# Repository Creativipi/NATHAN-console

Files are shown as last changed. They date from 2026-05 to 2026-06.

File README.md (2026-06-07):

# NATHAN Console

NATHAN Logo

## How it began

The NATHAN console was born from a desire to create something meaningful for an incredible person: **Nathan Therrien**.

I met Nathan in high school. He was one of those rare people who naturally brighten the world around them. Always smiling, always the first to say hello, to crack a joke, to make everyone around him feel good. We shared the same class in our final year, and even then, I was amazed by his radiant energy.

After high school, life took us in different directions. But I kept following Nathan online, especially through his Facebook page, where he shares videos of his musical explorations. Because yes, on top of everything else, **Nathan is an outstanding musician** and a passionate synthesizer enthusiast.

One morning in year 2022, Nathan made a post looking for help with 3D printing and soldering. At that time, I was just diving into the world of programming, microcontrollers, and digital fabrication. I was eager to learn and build something real. The moment I saw his message, I knew: **this was the project I had been waiting for**.

Working with Nathan, someone I had admired for years, gave me the perfect opportunity to grow my skills while collaborating with someone truly inspiring. He would be part of the process: designing the sounds, shaping the ideas, and even learning to code. From the start, the goal was clear: **build something together that he could one day fully own**.

Since 2022, this journey has become a shared adventure. Today, I’m proud to present the first version of the console:
**NATHAN — Narrative Audio Terminal for Humans with Alternative Navigation**.

As time becomes more limited for me, my hope is to pass the torch. I want the community to take this project further, to make it bigger, better, and even more inclusive.

---

## What is NATHAN?

**NATHAN** is an open source game console powered by a Raspberry Pi Pico, specifically designed for blind or visually impaired players.

Inspired by the form of an Xbox controller, the device includes:

* 5 tactile buttons
* 5 LED indicators
* An integrated audio output
  Together, these features enable an immersive and fully accessible gaming experience.

---

## Features

* 🎮 **Ergonomic form** – Inspired by the Xbox controller for comfortable use
* 🔘 **5 physical buttons** – Easily distinguishable for gameplay
* 💡 **5 LED indicators** – Optional visual feedback
* 🔊 **Audio output** – For immersive, sound-based gameplay
* ♿ **Inclusive game design** – Every game is made for accessibility

---

## Game Concept

Each game on the NATHAN console features a **blind protagonist named Nathan**.

The current flagship game, **NATHAN: Glassbreaker**, puts you in the role of Nathan, a hero who fights and navigates *only* through sound. It's a game where your ears become your eyes, and audio becomes your primary interface with the world. A game felt instead of seen.

---

## Open Source & Community

NATHAN is proudly open source.

This project is a call to creators, developers, makers, and dreamers:
**Let’s build accessible games together.**

Whether you want to:

* Design new games tailored for blind players
* Improve the hardware or firmware
* Suggest ideas to enhance the console
  Your contribution is welcome.

---

## Name Meaning

> **NATHAN** = *Narrative Audio Terminal for Humans with Alternative Navigation*

A console built around sound, for a hero and a community that navigates the world differently.

---

> 🎙️ *Together, let’s make gaming accessible to everyone.*

---

## 📚 Documentation & gouvernance

Toute la documentation projet vit dans [`docs/`](./docs/) :

- **[`docs/README.md`](./docs/README.md)** — *commencez ici* (parcours de lecture).
- **[Journal des décisions — ADR](./docs/decisions/README.md)** — *pourquoi* le projet est ainsi, et son évolution dans le temps.
- **[Specs](./docs/specs/)** · **[Planification & GANTT](./docs/planning/)** · **[Architecture](./docs/architecture/)**.
- **[CONTRIBUTING.md](./CONTRIBUTING.md)** — comment contribuer et **tracer une décision**.

---

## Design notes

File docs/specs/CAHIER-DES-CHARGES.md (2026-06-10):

# Cahier des Charges — Projet NATHAN Console (v2.0)

**Projet :** NATHAN — Narrative Audio Terminal for Humans with Alternative Navigation
**Version du document :** 2.0
**Date :** 2026-03-05
**Auteur :** Arthur Olivier Fortin
**Statut :** Phase de conception majeure

---

## Table des matières

1. [Contexte et vision du projet](#1-contexte-et-vision-du-projet)
2. [État actuel du projet (v1.0)](#2-état-actuel-du-projet-v10) — *inclut jeu existant GlassBreaker et IDE*
3. [Objectifs du projet majeur (v2.0)](#3-objectifs-du-projet-majeur-v20)
4. [Public cible](#4-public-cible)
5. [Équipes, rôles et stratégie de développement parallèle](#5-équipes-rôles-et-stratégie-de-développement-parallèle)
6. [Spécifications hardware (v2.0)](#6-spécifications-hardware-v20)
7. [Spécifications firmware et logiciel bas niveau](#7-spécifications-firmware-et-logiciel-bas-niveau)
8. [Spécifications du game engine](#8-spécifications-du-game-engine)
9. [Spécifications du premier jeu — La Maison de Nathan](#9-spécifications-du-premier-jeu--la-maison-de-nathan)
10. [Système de mini-jeux](#10-système-de-mini-jeux)
11. [Contraintes et risques techniques](#11-contraintes-et-risques-techniques)
12. [Planification par workstreams et dépendances](#12-planification-par-workstreams-et-dépendances)
13. [Budget](#13-budget)
14. [Livrables](#14-livrables)

---

## 1. Contexte et vision du projet

### 1.1 Origine

Le projet NATHAN est né en 2022 d'une collaboration entre Arthur Olivier Fortin et une personne non-voyante, musicien et passionné de synthétiseurs. L'objectif initial était de concevoir une console de jeu entièrement accessible aux personnes non-voyantes, dans laquelle le son et les sensations tactiles remplacent intégralement l'image. Le projet est réalisé en partenariat avec l'APHVE (Association des Personnes Handicapées Visuelles de l'Estrie), qui accompagne l'équipe avec un groupe d'utilisateurs non-voyants tout au long du développement.

### 1.2 Mission

Créer une console de jeu **open-source**, **abordable** et **inclusive**, où l'expérience est entièrement auditive et haptique. La console doit permettre à un utilisateur non-voyant de jouer les yeux fermés, avec une immersion complète par le son spatial 3D et le retour vibratoire directionnel.

### 1.3 Vision long terme

- Être la première console de jeu grand public dédiée aux personnes ayant une déficience visuelle.
- Permettre aux utilisateurs de **créer leurs propres mini-jeux** sans barrière technique (MicroPython).
- Constituer une **plateforme pédagogique** : initiation à la programmation pour les personnes non-voyantes.
- Rester open-source pour favoriser la contribution communautaire.

---

## 2. État actuel du projet (v1.0)

### 2.1 Ce qui est complété

| Composant | État | Détails |
|---|---|---|
| Modèles 3D boîtier | ✅ Complet | 3 pièces SolidWorks (.SLDPRT, importables dans Onshape — géométrie conservée), STL générés |
| PCB KiCAD | ✅ Complet | Gerbers prêts pour fabrication |
| BOM (liste de matériaux) | ✅ Documenté | Composants sourcés |
| Documentation README | ✅ Rédigé | Histoire, vision, fonctionnalités |

### 2.2 Matériel actuel (v1.0)

| Composant | Spécification |
|---|---|
| Microcontrôleur | Raspberry Pi Pico (RP2040) |
| Boutons | 5 (3 arcade 30mm + 2 micro switches) |
| LEDs | 5 (indicateurs visuels) |
| Moteurs haptiques | 2 (moteurs Xbox rumble) |
| Audio | Jack stéréo 3.5mm |
| Stockage | Module micro SD |
| Alimentation | 3x piles AA |
| Potentiomètre | WH148 1kΩ |

### 2.3 Ce qui n'existe pas encore (côté console v2.0)

- Firmware embarqué : **non démarré** (à écrire en C/C++, MCU à déterminer)
- Game engine spatial : **non démarré**
- IDE mini-jeux (intégration NATHAN) : **en cours** (voir 2.5)

### 2.4 Jeu existant — GlassBreaker (CircuitPython, Raspberry Pi Pico)

Un jeu complet est déjà fonctionnel dans le dépôt `NATHAN-code`. Il tourne sur le **Raspberry Pi Pico** en **CircuitPython 8.x** et constitue la référence directe pour l'architecture des mini-jeux futurs.

**Dépôt :** `C:\Users\arthu\OneDrive\NATHAN\NATHAN-code` (GlassBreaker Safe CP)

#### Architecture du jeu existant

```
GlassBreaker Safe CP/
├── main.py              # Orchestre tous les managers
├── input/buttons.py     # ButtonManager — lecture GPIO
├── output/audio.py      # AudioManager — PWM 22050Hz mono
├── output/leds.py       # LEDManager — 7 LEDs
├── output/motors.py     # MotorManager — 2 moteurs rumble
├── game/logic.py        # GameLogic + GameState
├── game/menu.py         # MenuSystem + MenuExtension
├── utils/memory.py      # MemoryManager — scores SD card
├── sounds/              # Fichiers WAV sur carte SD
└── lib/                 # Bibliothèques Adafruit CircuitPython
```

#### Mécaniques de jeu

- **Type :** Jeu de réaction bouton (audio-first)
- **5 modes :** Arcade (sons), Voice (voix), Reverse, Light (visuel), Megamix (aléatoire)
- **Difficulté progressive :** `timeout = max(0.5, 1.0 - (0.001 × score))`
- **Jalons :** Annonces audio à 25, 50, 75, 100 points
- **Persistance :** High scores par mode sur carte SD (FAT32)

#### Ce que cela implique pour v2.0

| Aspect | GlassBreaker (v1) | NATHAN v2.0 |
|---|---|---|
| Langage jeu | CircuitPython | C/C++ (game engine) |
| Langage mini-jeux | CircuitPython | MicroPython (quasi-identique) |
| Audio | PWM mono 22050 Hz | I2S stéréo binaural HRTF |
| Entrées | 5 boutons | 2 joysticks + boutons |
| Haptique | 2 moteurs (on/off) | 5 moteurs arc (PWM intensité) |
| Pattern module | Manager + MenuExtension | HAL + API game engine |

> **Note de compatibilité :** CircuitPython et MicroPython partagent ~95% de leur syntaxe. Les mini-jeux écrits pour v2.0 s'inspireront directement des modules GlassBreaker. Le `MenuExtension` pattern existant (classe avec `run()` et métadonnées) devient le modèle du format mini-jeu MicroPython.

#### Pattern MenuExtension (référence pour le format mini-jeu)

```python
# Modèle inspiré de game/menu.py (GlassBreaker)
class MonMiniJeu:
    META = {
        "title": "Mon Mini-Jeu",
        "author": "Arthur",
        "description": "Description audio du jeu"
    }

    def __init__(self, managers):
        self.audio = managers["audio"]
        self.buttons = managers["buttons"]
        self.motors = managers["motors"]

    def run(self):
        """Boucle principale — retourne True si succès, False si échec"""
        pass
```

### 2.5 IDE de programmation (Electron + React + TypeScript)

L'IDE fait partie intégrante du projet NATHAN. C'est l'application desktop qui permet aux utilisateurs (y compris non-voyants) de programmer et de transférer des mini-jeux sur la console.

**Stack :** Electron 28 + React 18 + TypeScript 5.3 + Vite 5

#### Ce qui est déjà implémenté dans l'IDE

| Fonctionnalité | État | Détail |
|---|---|---|
| Éditeur de code multi-onglets | ✅ Complet | Textarea + coloration syntaxique custom |
| Explorateur de fichiers (sidebar) | ✅ Complet | Arborescence avec create/delete |
| Recherche & remplacement | ✅ Complet | Case-insensitive, replace-all |
| Terminal intégré | ✅ Complet | Exécution de commandes shell avec streaming |
| Accessibilité vocale (TTS) | ✅ Complet | Web Speech API, **français par défaut (fr-FR)** |
| Screen reader (ARIA live) | ✅ Complet | Annonces assistives |
| Raccourcis clavier | ✅ Complet | Ctrl+F, Ctrl+S, Ctrl+Shift+P, etc. |
| Palette de commandes | ✅ Complet | Ctrl+Shift+P |
| Maestro backend (IA, C# .NET) | ✅ Intégré | Sidecar HTTP, agent "Jarvis" (ask) |
| Coloration syntaxique TypeScript/JS | ✅ Complet | Tokenizer regex custom |

#### Ce qui reste à développer dans l'IDE pour NATHAN

| Fonctionnalité | Priorité | Notes |
|---|---|---|
| Coloration syntaxique MicroPython | Critique | Remplacer/compléter le tokenizer TS |
| Auto-complétion API `nathan.*` | Critique | Nécessite Monaco Editor ou extension |
| Communication USB série (console) | Critique | Web Serial API ou `serialport` npm |
| Upload de `.py` vers carte SD via USB | Critique | Dépend de la communication USB |
| Visualisateur de scène 2D (sons spatiaux) | Haute | Drag & drop, coordonnées x/y/z |
| Simulation audio WebAudio HRTF | Moyenne | Aperçu avant envoi sur console |
| Gestionnaire de mini-jeux (liste SD) | Haute | Lecture liste depuis console |
| Mode d'affichage accessible (grand texte, contraste) | Haute | Accessibilité DV |

> L'IDE est développé dans le cadre de ce projet sous `ide/`. L'intégration avec la console NATHAN se fait via le protocole USB CDC défini dans la section 7.4.

---

## 3. Objectifs du projet majeur (v2.0)

Le projet v2.0 constitue une **refonte complète** articulée autour de quatre axes :

### Axe 1 — Refonte hardware
Remplacer le Raspberry Pi Pico par un **microcontrôleur adapté** (choisi après benchmark), ajouter **2 joysticks analogiques**, **5 moteurs de vibration en arc**, et migrer vers une **batterie LiPo USB-C rechargeable**.

### Axe 2 — Game engine embarqué
Développer un moteur de jeu en **C/C++** tournant sur le microcontrôleur choisi, avec un système de placement 2D+hauteur permettant le calcul automatique d'**audio spatial binaural (HRTF)**.

### Axe 3 — Premier jeu : La Maison de Nathan
Développer le jeu de démonstration de la console : un jeu entièrement auditif et haptique mettant en scène Nathan, un aveugle, dans sa maison.

### Axe 4 — Système de mini-jeux
Permettre aux utilisateurs de programmer et jouer à des mini-jeux écrits en **MicroPython** via l'IDE du projet.

---

## 4. Public cible

### 4.1 Utilisateurs finaux (joueurs)

- **Primaire :** Personnes non-voyantes ou malvoyantes, tous âges
- **Secondaire :** Personnes voyantes souhaitant une expérience sensorielle immersive

### 4.2 Utilisateurs créateurs (programmeurs de mini-jeux)

- **Primaire :** Personnes non-voyantes apprenant la programmation
- **Secondaire :** Développeurs souhaitant créer du contenu pour la plateforme
- **Niveau requis :** Débutant (MicroPython simplifié, interface graphique)

### 4.3 Contraintes d'accessibilité prioritaires

- Toute interface de jeu doit fonctionner **sans retour visuel**
- Tous les menus et interactions doivent être **entièrement navigables au son**
- Le boîtier doit être **ergonomique** et les contrôles **facilement différenciables au toucher**

---

## 5. Équipes, rôles et stratégie de développement parallèle

### 5.1 Composition des équipes

| Équipe | Code | Profil | Responsabilité |
|---|---|---|---|
| **Électrique** | ELEC | Génie électrique | Schéma, PCB, boîtier, soudure, validation matérielle |
| **Engine** | ENG | Génie informatique | Game engine, scènes, collisions, bâton, MicroPython, HAL |
| **Audio spatial** | AUD | Génie informatique (spécialisé signal/audio) | Pipeline HRTF, mix binaural, évaluation software vs DSP |
| **Jeu / Contenu** | JEU | Génie informatique / design | Design des pièces, mécaniques de jeu, banque de sons, narration |

### 5.2 Principe fondamental : zéro temps d'attente entre équipes

Le plan de développement est conçu pour que **aucune équipe ne soit bloquée** par une autre. Cela repose sur trois stratégies :

#### Stratégie A — Manette de substitution (découple ELEC ↔ ENG/JEU)

Dès le **jour 1** du projet, les équipes logicielles utilisent une **manette USB grand public** (type DualShock 4 / Xbox One, ~30$ CAD) pour développer et tester toute la logique de jeu.

Un module **InputMapper** abstrait complètement le matériel :

```
┌───────────────────────────────────────────────┐
│                 Game Engine                     │
│                                                 │
│    scene.update(input, dt)                      │
│         │                                       │
│    ┌────▼─────┐                                 │
│    │InputMapper│  ← Interface abstraite          │
│    └────┬─────┘                                 │
│         │                                       │
│    ┌────┴──────────────┬──────────────────┐     │
│    │                   │                  │     │
│  GamepadMapper    NathanMapper       DebugMapper│
│  (DualShock/Xbox) (manette réelle)   (clavier)  │
│  PHASE 1-2        PHASE 3+           DEBUG      │
└───────────────────────────────────────────────┘
```

| Implémentation | Utilisée par | Phase | Description |
|---|---|---|---|
| `GamepadMapper` | ENG, JEU, AUD | Phases 1-2 | Manette USB standard. Joystick L/R mappés directement, vibration mono simulée. |
| `DebugMapper` | ENG | Toutes | Clavier + souris pour tests rapides sans manette |
| `NathanMapper` | ENG, ELEC | Phase 3+ | Manette NATHAN réelle. Joysticks ADC, 5 moteurs PWM, boutons GPIO. |

**Mapping de substitution (GamepadMapper):**

| Contrôle NATHAN | Substitut DualShock/Xbox |
|---|---|
| Joystick gauche | Joystick gauche (identique) |
| Joystick droite | Joystick droite (identique) |
| Boutons A/B/C | ×/○/△ (ou A/B/Y) |
| Gâchettes L1/R1 | L1/R1 (identique) |
| 5 moteurs arc | Vibration unique du gamepad (intensité = moteur central) |
| Start/Select | Start/Select (identique) |

**Pour le haptique**, le gamepad n'a qu'un moteur. Le GamepadMapper simule les 5 moteurs en arc par :
- Vibration unique pour tout contact de bâton
- Logs console indiquant quel moteur NATHAN serait activé (pour debug)
- La validation réelle des 5 moteurs se fait à la Phase 3 (intégration)

#### Stratégie B — Développement audio PC-first (découple AUD ↔ ELEC)

Le développeur audio ne touche **jamais** au microcontrôleur avant la Phase 3. Tout le développement HRTF se fait sur PC :

```
Phase 1 : Recherche + prototypage PC (C/C++ + miniaudio ou libsoundio)
Phase 2 : Module audio spatial fonctionnel sur PC, testé au casque
Phase 3 : Portage vers le MCU choisi, benchmark CPU/latence
Phase 3b: Décision : software pur OU ajout DSP matériel externe
```

L'interface entre le game engine et le module audio est un **contrat** défini dès la Phase 0 (voir 5.3). Tant que le contrat est respecté, les implémentations PC et ESP32 sont interchangeables.

#### Stratégie C — Contrats d'interface (découple toutes les équipes)

Avant tout développement, les équipes définissent ensemble les **interfaces contractuelles** entre les modules. Chaque interface a une **implémentation stub** qui permet de tester sans dépendance.

### 5.3 Contrats d'interface (Phase 0 — à définir en priorité)

Les 5 contrats suivants sont les **premiers livrables du projet**. Ils doivent être définis et validés par toutes les équipes avant le début du développement.

#### Contrat 1 — InputMapper (ENG ↔ ELEC)

```c
// Abstraction des entrées : toute source d'input implémente cette interface
typedef struct {
    float left_x, left_y;     // Joystick gauche (-1.0 à 1.0)
    float right_x, right_y;   // Joystick droite (-1.0 à 1.0)
    bool buttons[9];           // A, B, C, L1, R1, L2, R2, Start, Select
    bool left_click;           // Joystick gauche appuyé
    bool right_click;          // Joystick droite appuyé
} InputState;

void input_mapper_init(void);
InputState input_mapper_read(void);
```

#### Contrat 2 — SpatialAudioEngine (ENG ↔ AUD)

```c
// Abstraction audio : le game engine place des sons, l'implémentation les rend binauraux
typedef int SoundHandle;

void spatial_audio_init(int sample_rate, int max_sources);
void spatial_audio_shutdown(void);

SoundHandle spatial_audio_play(const char* wav_path, float x, float y, float z, bool loop);
void spatial_audio_stop(SoundHandle h);
void spatial_audio_set_position(SoundHandle h, float x, float y, float z);
void spatial_audio_set_volume(SoundHandle h, float vol);

void spatial_audio_update_listener(float px, float py, float orientation_deg);
void spatial_audio_render(int16_t* stereo_buffer, int frame_count);

// Ambiance (non spatialisé, stéréo direct)
void spatial_audio_play_ambient(const char* wav_path, float volume);
void spatial_audio_stop_ambient(void);
```

**Implémentations prévues :**

| Implémentation | Utilisée par | Phase | Backend |
|---|---|---|---|
| `StubAudio` | ENG | Phase 1 | Pas de son, logs console uniquement |
| `PCAudio` | AUD, JEU | Phase 1-2 | `miniaudio` + HRTF sur PC |
| `EmbeddedAudio` | Tous | Phase 3+ | I2S + DAC + HRTF embarqué (MCU choisi après benchmark) |

#### Contrat 3 — HapticEngine (ENG ↔ ELEC)

```c
// Abstraction haptique : 5 moteurs logiques en arc
// Motor IDs : 0=extrême gauche, 1=gauche, 2=centre, 3=droite, 4=extrême droite

void haptic_init(void);
void haptic_pulse(int motor_id, float intensity, int duration_ms);
  // motor_id: 0-4, intensity: 0.0-1.0
void haptic_sweep(float direction, float intensity);
  // direction: -1.0 (gauche) → 1.0 (droite)
void haptic_pattern(const char* pattern_name);
  // Patterns prédéfinis: "cane_wall", "cane_floor", "cane_sweep", "hit", "strum"
void haptic_stop_all(void);
```

**Implémentations prévues :**

| Implémentation | Phase | Comportement |
|---|---|---|
| `StubHaptic` | Phase 1 | Logs console uniquement |
| `GamepadHaptic` | Phase 1-2 | Vibration unique du gamepad USB |
| `NathanHaptic` | Phase 3+ | 5 moteurs PWM réels via GPIO du MCU choisi |

#### Contrat 4 — StorageProvider (ENG)

```c
void storage_init(void);
bool storage_file_exists(const char* path);
int  storage_read_file(const char* path, uint8_t* buffer, int max_size);
int  storage_write_file(const char* path, const uint8_t* data, int size);
char** storage_list_dir(const char* path, int* count);
```

#### Contrat 5 — MiniGameRunner (ENG)

```c
typedef struct {
    char title[64];
    char author[32];
    char description[128];
} MiniGameMeta;

bool minigame_load(const char* dir_path);
MiniGameMeta minigame_get_meta(void);
bool minigame_setup(void);
bool minigame_loop(void);  // retourne false quand le mini-jeu se termine
void minigame_unload(void);
```

### 5.4 Matrice de responsabilité (RACI)

| Livrable | ELEC | ENG | AUD | JEU |
|---|---|-----|-----|-----|
| Schéma / PCB (MCU choisi) | **R** | C | — | — |
| Boîtier v2.0 (Onshape) | **R** | C | — | — |
| Soudure et validation matérielle | **R** | — | — | — |
| Contrats d'interface (Phase 0) | C | **R** | C | I |
| InputMapper (toutes implémentations) | C | **R** | — | — |
| Game engine (scènes, collisions, bâton) | — | **R** | — | I |
| Pipeline HRTF (recherche + implémentation) | — | I | **R** | — |
| Portage audio embarqué | C | I | **R** | — |
| Intégration MicroPython | — | **R** | — | I |
| Design des pièces du jeu | — | I | I | **R** |
| Banque de sons et musiques | — | — | C | **R** |
| Narration audio (tutoriel, voix personnage) | — | — | — | **R** |
| Mécaniques guitare/batterie | — | C | C | **R** |
| Tests d'intégration finale | C | **R** | C | C |
| Tests utilisateur (groupe DV via APHVE) | I | C | C | **R** |
| IDE de programmation | — | **R** | — | C |

> **R** = Responsable, **C** = Consulté, **I** = Informé

---

## 6. Spécifications hardware (v2.0)

### 6.1 Microcontrôleur — À déterminer

Le microcontrôleur sera choisi **après le benchmark du jeu sur PC**, qui mesurera les besoins réels en CPU, RAM et I/O. Cette décision est le jalon clé du chemin critique (voir `TACHES.md`).

**Besoins minimaux identifiés :**

| Paramètre | Besoin minimum | Justification |
|---|---|---|
| CPU | >= 2 cœurs, >= 160 MHz | Un cœur dédié au rendu audio HRTF, un à la logique de jeu |
| RAM | >= 4 MB (PSRAM) | Tables HRTF (~1 MB) + buffers audio + game engine + MicroPython |
| Flash | >= 8 MB | Firmware + interpréteur MicroPython |
| I2S | >= 1 interface stéréo | Connexion au DAC audio externe |
| ADC | >= 4 canaux, >= 10 bits | 2 joysticks × 2 axes |
| PWM | >= 5 canaux | 5 moteurs haptiques individuels |
| USB | USB OTG ou CDC natif | Communication avec l'IDE (port série virtuel) |
| SPI | >= 1 | Lecteur carte micro SD |
| GPIO | >= 9 numériques | 7 boutons + 2 clicks joystick |

**Candidats préliminaires** (analyse détaillée dans le MIP) :

| MCU | CPU | RAM | I2S | USB | Prix (~) |
|-----|-----|-----|-----|-----|---|
| ESP32-S3 | 2× 240 MHz | 8 MB PSRAM | 2× | USB OTG natif | ~5$ |
| RP2350 | 2× 150 MHz | 520 KB + ext | 2× | USB 1.1 | ~1$ |
| STM32H7 | 1× 480 MHz | 1 MB + ext | 2× | USB OTG | ~10$ |

> Le choix final sera documenté dans un **rapport de justification quantitatif** basé sur le benchmark PC (voir `TACHES.md`, jalon "Choix du MCU").

### 6.2 Système audio

**Le DAC audio sera choisi en même temps que le MCU.** Les besoins sont :

| Paramètre | Besoin |
|---|---|
| Interface | I2S (compatible avec le MCU choisi) |
| Résolution | >= 16 bits, >= 44.1 kHz |
| SNR | >= 80 dB |
| Sortie | Jack stéréo 3.5mm (casque uniquement) |

**Note importante :** Le jeu est conçu pour une écoute au **casque stéréo uniquement**. Le son spatial binaural (HRTF) requiert un casque pour l'effet 3D.

#### Pipeline audio spatial

```
Positions 3D des sons (via SpatialAudioEngine)
        ↓
Calcul azimut/élévation/distance
        ↓
Application HRTF (lookup table, MIT KEMAR ou équivalent open-source)
        ↓
Mix audio binaural (canal L + canal R)
        ↓
Buffer DMA → I2S → DAC → Jack 3.5mm
```

#### Format audio des assets

- Samples : **WAV 16 bits, 44.1 kHz, mono** (le moteur applique la spatialisation)
- Musiques d'ambiance : **WAV 16 bits, 44.1 kHz, stéréo** (non spatiales, lecture directe)
- Stockage sur carte micro SD

### 6.3 Système haptique — 5 moteurs en arc

#### Topologie

Les 5 moteurs vibrants sont disposés en arc de cercle dans le corps de la manette :

```
Position physique :  [M0]  [M1]  [M2]  [M3]  [M4]
Direction simulée :  ←←   ←     ↑     →     →→
```

#### Spécifications moteurs

| Paramètre | Valeur |
|---|---|
| Type | Moteur à vibration excentrique (ERM) ou LRA |
| Tension nominale | 3V |
| Contrôle | PWM individuel par canal (intensité variable) |
| Driver | MOSFET N-CH par moteur (ex: 2N7002) OU DRV2605L (recommandé) |
| Fréquence PWM | 1 kHz minimum |

#### Cas d'usage

| Interaction | Moteurs activés | Pattern |
|---|---|---|
| Bâton touche mur à gauche | M0, M1 | Impulsion courte, forte |
| Bâton touche sol | M0 à M4 (tous, faible) | Vibration continue faible |
| Bâton touche obstacle à droite | M3, M4 | Impulsion courte, forte |
| Coup de bâton en combat | M0 à M4 (séquence) | Sweep directionnel |
| Guitare — strumming | M2, M3 | Vibration rhythmique |
| Drum — impact | M correspondant à la zone | Impulsion forte courte |

### 6.4 Entrées utilisateur

#### Joysticks

| Paramètre | Valeur |
|---|---|
| Quantité | 2 (gauche + droite) |
| Type | Joystick analogique double axe (modèle Xbox/PS) |
| Résolution ADC | 12 bits (0–4095) |
| Canaux requis | 4 entrées ADC (X/Y par joystick) |
| Bouton intégré | Oui (appui joystick = bouton numérique) |

#### Boutons

| Bouton | Type | Usage principal |
|---|---|---|
| A (×) | Arcade 30mm | Action principale |
| B (○) | Arcade 30mm | Action secondaire |
| C (△) | Arcade 30mm | Action tertiaire / menu |
| L1 | Micro switch | Gâchette gauche |
| R1 | Micro switch | Gâchette droite |
| Start | Bouton tactile | Menu / pause |
| Select | Bouton tactile | Retour / annuler |

### 6.5 Alimentation

| Paramètre | Besoin |
|---|---|
| Batterie | LiPo 1S (3.7V) — capacité min. 2000 mAh |
| Connecteur de charge | USB-C |
| Protection | Surcharge, décharge profonde, court-circuit |
| Régulateur | LDO 3.3V pour le MCU |
| Autonomie cible | >= 4 heures en usage typique |

> L'estimation de consommation détaillée sera calculée une fois le MCU et le DAC choisis.

### 6.6 Connectivité

| Interface | Usage |
|---|---|
| USB-C | Charge + connexion à l'IDE NATHAN (USB CDC) |
| Wi-Fi 2.4 GHz | Mise à jour OTA (optionnel v2.0) |
| Micro SD | Stockage assets audio, jeux, mini-jeux |

### 6.7 Boîtier (refonte ergonomique)

#### Contraintes de refonte

- Intégrer 2 joysticks (gauche + droite)
- Intégrer 5 moteurs en arc dans les poignées
- Passer à une batterie LiPo + port USB-C
- Conserver l'inspiration Xbox pour l'ergonomie
- Rester fabricable par impression 3D FDM
- **Dimensions maximales :** Tenir dans une main adulte (largeur ~16 cm)

#### Fichiers à mettre à jour

- `CAD_Files/Console/NATHAN-console-asm.SLDASM` — refonte complète
- `CAD_Files/Console/parts/*.SLDPRT` — toutes les pièces
- `3D Print Models/*.STL` — regenerer depuis les nouveaux SLDPRT
- `CAD_Files/PCB/` — nouveau schéma et PCB pour le MCU choisi

---

## 7. Spécifications firmware et logiciel bas niveau

### 7.1 Environnement de développement

| Paramètre | Valeur |
|---|---|
| SDK | Dépend du MCU choisi (ex: ESP-IDF, Pico SDK, STM32 HAL) |
| Langage principal | C / C++17 |
| Build system | CMake |
| Tests | Unity test framework (embarqué) |

> Le SDK et les outils de débogage seront déterminés après le choix du MCU.

### 7.2 Architecture firmware

```
┌─────────────────────────────────────────────────────────┐
│                      APPLICATION                         │
│  ┌─────────────┐  ┌──────────────┐  ┌────────────────┐  │
│  │  Game Engine │  │ MicroPython  │  │   USB Bridge   │  │
│  │   (C/C++)   │  │  Sandbox     │  │   (CDC)        │  │
│  └──────┬──────┘  └──────┬───────┘  └───────┬────────┘  │
│         └────────────────┴──────────────────┘            │
│  ┌─────────────────────────────────────────────────────┐ │
│  │         Contrats d'interface (section 5.3)          │ │
│  │  InputMapper | SpatialAudioEngine | HapticEngine    │ │
│  └─────────────────────────────────────────────────────┘ │
│  ┌─────────────────────────────────────────────────────┐ │
│  │              Hardware Abstraction Layer (HAL)        │ │
│  │  NathanMapper | ESP32Audio | NathanHaptic | Storage │ │
│  └─────────────────────────────────────────────────────┘ │
│  ┌──────────┐ ┌────────┐ ┌────────┐ ┌────────┐          │
│  │ ESP-IDF  │ │FreeRTOS│ │  I2S   │ │  SPI   │          │
│  └──────────┘ └────────┘ └────────┘ └────────┘          │
└─────────────────────────────────────────────────────────┘
```

### 7.3 Tâches FreeRTOS

| Tâche | Priorité | Core | Rôle |
|---|---|---|---|
| `task_audio_render` | Très haute | Core 0 | Rendu HRTF + DMA I2S |
| `task_game_logic` | Haute | Core 1 | Logique de jeu, état |
| `task_input_poll` | Haute | Core 1 | Lecture entrées via InputMapper à 100 Hz |
| `task_haptic_ctrl` | Moyenne | Core 1 | Contrôle moteurs via HapticEngine |
| `task_usb_bridge` | Basse | Core 1 | Communication USB avec IDE NATHAN |
| `task_sd_io` | Basse | Core 0 | Lecture assets depuis SD |

### 7.4 Protocole USB CDC (pont avec l'IDE NATHAN)

Le firmware expose un port série virtuel (USB CDC) avec un protocole simple :

| Commande | Direction | Description |
|---|---|---|
| `LIST` | IDE → Console | Lister les mini-jeux sur SD |
| `UPLOAD <path> <size>` | IDE → Console | Envoyer un fichier vers SD |
| `DELETE <path>` | IDE → Console | Supprimer un fichier sur SD |
| `LOG` | Console → IDE | Stream des logs/erreurs en temps réel |
| `META <path>` | IDE → Console | Lire les métadonnées d'un mini-jeu |

> C'est l'unique point de contact entre ce projet et l'IDE. Tant que ce protocole est respecté, les deux projets évoluent indépendamment.

### 7.5 Support MicroPython embarqué

Le firmware intègre un interpréteur **MicroPython** via la bibliothèque `micropython-embed` compilée en tant que composant ESP-IDF.

**Note de continuité :** Le jeu existant GlassBreaker tourne en CircuitPython sur Pico. MicroPython et CircuitPython partagent la même syntaxe Python et des APIs très proches — le passage à MicroPython pour v2.0 est transparent pour les mini-jeux.

- Les mini-jeux sont des fichiers `.py` sur la carte SD (dossier `/sd/minigames/`)
- L'interpréteur est lancé dans un contexte sandboxé avec accès limité aux APIs HAL
- Un module C expose l'API du moteur à MicroPython :
  - `nathan.audio.play(sound_id, x, y, z)`
  - `nathan.haptic.pulse(motor, intensity)`
  - `nathan.input.read_joystick(id)` → `(x, y)`
  - `nathan.input.read_button(id)` → `bool`
- Les sons des mini-jeux sont stockés dans `/sd/minigames/<nom_jeu>/sounds/`

---

## 8. Spécifications du game engine

### 8.1 Philosophie du moteur

Le moteur est conçu pour un jeu **entièrement auditif**. Il n'y a pas de rendu graphique. Le "monde" est une grille 2D avec une coordonnée de hauteur. Les sons sont les seuls retours d'état du monde.

**Toute interaction avec le hardware passe par les contrats d'interface (section 5.3).** Le game engine n'appelle jamais directement I2S, GPIO, ou ADC.

### 8.2 Représentation du monde

#### Espace de coordonnées

```
        Y (profondeur)
        ^
        |
        |    * Son à (x=2, y=3, z=1)
        |
        +----------→ X (droite/gauche)

Z = hauteur (sol=0, plafond=3m env.)
Joueur toujours à Z=0 (sol)
```

- Grille 2D en centimètres entiers
- Hauteur Z flottante (0.0 à 3.0 m typiquement)
- Le joueur a une position `(px, py)` et une orientation `θ` (angle en degrés)

#### Calcul HRTF (responsabilité de l'équipe AUD)

Pour chaque source sonore à `(sx, sy, sz)` avec le joueur en `(px, py)` orienté à `θ` :

```
dx = sx - px
dy = sy - py
distance = sqrt(dx² + dy² + sz²)
azimut = atan2(dy, dx) - θ   (relatif à l'orientation du joueur)
élévation = atan2(sz, sqrt(dx² + dy²))
```

Application d'une HRTF lookup table (MIT KEMAR dataset, open-source, 187 positions) :
- Sélection des 2 HRTF les plus proches par interpolation
- Atténuation par distance : `gain = 1 / (1 + distance * k)`
- Rendu stéréo par convolution avec les réponses impulsionnelles HRTF gauche/droite

> **Note équipe AUD :** Le game engine fournit les positions via `spatial_audio_update_listener()` et `spatial_audio_set_position()`. Le calcul HRTF est entièrement encapsulé dans le module audio. L'équipe AUD est libre de choisir l'algorithme, la taille des filtres, et l'implémentation tant que l'API du contrat 2 est respectée.

### 8.3 API du game engine

```cpp
// Gestion de scène
Scene* scene_create(const char* name);
void scene_load(Scene* s);
void scene_unload(Scene* s);

// Entités sonores (délègue au SpatialAudioEngine)
SoundEntity* entity_create(float x, float y, float z, const char* sound_file);
void entity_set_position(SoundEntity* e, float x, float y, float z);
void entity_set_looping(SoundEntity* e, bool loop);
void entity_play(SoundEntity* e);
void entity_stop(SoundEntity* e);

// Joueur
void player_set_position(float x, float y);
void player_set_orientation(float angle_deg);
void player_move(float dx, float dy);

// Collisions (murs/obstacles)
void world_add_wall(float x1, float y1, float x2, float y2);
bool world_check_collision(float x, float y, float radius);

// Audio ambiant (non spatial, via SpatialAudioEngine)
void ambient_play(const char* sound_file, float volume);
void ambient_stop();

// Haptique (délègue au HapticEngine)
void engine_haptic_cane(float contact_x, float contact_y);
```

### 8.4 Système de collisions et bâton

Le bâton d'aveugle est simulé comme un **rayon** (raycast) partant du joueur dans la direction du joystick droit.

```
Joueur (px, py)
      \
       \  ← direction joystick droit
        \
         * point de contact (cx, cy)
         |
         | MURS ou OBSTACLES
```

- La distance au contact détermine l'intensité de vibration (proche = plus fort)
- La direction du contact (gauche/droite/avant) détermine quels moteurs activés
- Le son de frottement change selon la surface (bois, béton, herbe) via le tag de surface du mur

---

## 9. Spécifications du premier jeu — La Maison de Nathan

### 9.1 Concept général

**Titre :** La Maison de Nathan
**Genre :** Jeu de vie / exploration sensorielle
**Perspective :** Première personne sonore (FPS audio)
**Durée :** Jeu ouvert (exploration libre + quêtes)

Le joueur incarne **Nathan**, un adolescent aveugle. Il doit accomplir des tâches quotidiennes, explorer sa maison, jouer de la musique, aller à l'école, et affronter des adversaires imaginaires avec son bâton.

### 9.2 Structure de la maison

```
┌─────────────────────────────────────────────────────┐
│                                                     │
│  ┌──────────┐  ┌──────────┐  ┌────────────────┐    │
│  │  CUISINE │  │  SALON   │  │    CHAMBRE     │    │
│  │          │  │  (HUB)   │  │                │    │
│  └──────────┘  └────┬─────┘  └────────────────┘    │
│                     │                               │
│  ┌──────────┐  ┌────┴─────┐  ┌────────────────┐    │
│  │ SALLE DE │  │          │  │  SALLE DE      │    │
│  │ MUSIQUE  │  │ COULOIR  │  │  MINI-JEUX     │    │
│  │          │  │          │  │                │    │
│  └──────────┘  └────┬─────┘  └────────────────┘    │
│                     │                               │
│             ┌───────┴──────┐                        │
│             │    ÉCOLE     │                        │
│             │  (extérieur) │                        │
│             └──────────────┘                        │
└─────────────────────────────────────────────────────┘
```

### 9.3 Pièce 1 — Le Salon (Hub principal)

**Rôle :** Point de départ et hub de navigation.

**Audio :** Musique d'ambiance douce (genre lo-fi / jazz calme). Sons de la maison : horloge, ventilation, sons extérieurs filtrés.

**Gameplay :**
- Premier endroit où le joueur apprend à se déplacer avec le joystick gauche
- Apprentissage de la navigation au son (chaque pièce a une signature musicale)
- Tutoriel intégré au jeu (voix du personnage explique ses sens)

**Éléments interactifs :**
- Canapé (son d'assise)
- Téléviseur (son — Nathan écoute un programme audio)
- Fenêtre (sons extérieurs, météo)

### 9.4 Pièce 2 — La Cuisine

**Audio :** Musique rythmée type jazz. Sons de cuisine (réfrigérateur, eau, vaisselle).

**Mini-jeu principal : Faire à manger**
- Objectif : Suivre une recette audio étape par étape
- Mécanique : Les joysticks imitent des gestes culinaires (mélanger = rotation joystick gauche, couper = up/down joystick droit)
- Feedback haptique : résistance simulée selon la texture des aliments
- Succès/échec évalué par la précision du geste et le timing

**Éléments interactifs :**
- Réfrigérateur (inventaire d'ingrédients, son caractéristique)
- Casserole (sons de cuisson évolutifs)
- Robinet (son de l'eau)

### 9.5 Pièce 3 — La Chambre

**Audio :** Musique calme / ASMR. Sons de chambre (ventilateur, pluie sur la fenêtre, horloge).

**Mini-jeux :**
- **Se lever le matin :** réveil, s'habiller (séquence de boutons au son)
- **Exploration libre :** Fouiller les tiroirs, découvrir des souvenirs audio

**Éléments interactifs :**
- Lit (point de sauvegarde)
- Radio (change la musique d'ambiance)
- Bureau (accès aux devoirs — mini-jeu de mémorisation sonore)

### 9.6 Pièce 4 — La Salle de Musique

**Audio :** Selon l'instrument joué. Réverbération de pièce simulée.

#### Instrument 1 — La Guitare

| Contrôle | Action |
|---|---|
| Joystick gauche (vertical) | Sélection de case (montée/descente sur le manche) |
| Joystick gauche (horizontal) | Sélection de corde |
| Joystick droit (vertical rapide ↓) | Strum vers le bas |
| Joystick droit (vertical rapide ↑) | Strum vers le haut |
| Bouton A | Accord de base (accord ouvert) |
| Bouton B | Accord barré |
| Bouton C | Accord spécial / sustain |

**Sons :** Samples de guitare acoustique réelle (banque de sons, licence libre).
**Feedback haptique :** Vibration légère des moteurs à chaque strum.

#### Instrument 2 — La Batterie

| Contrôle | Action |
|---|---|
| Joystick gauche ↑ | Grosse caisse (kick drum) |
| Joystick gauche ↓ | Charleston fermé (hi-hat closed) |
| Joystick gauche ← | Tom basse |
| Joystick gauche → | Tom aigu |
| Joystick droit ↑ | Snare |
| Joystick droit ↓ | Charleston ouvert (hi-hat open) |
| Gâchette L1 | Cymbale crash gauche |
| Gâchette R1 | Cymbale crash droite |
| Joystick droit appuyé | Ride cymbal |

**Sons :** Samples de batterie acoustique (banque libre).
**Feedback haptique :** Impact fort et court sur le/les moteurs correspondants.

**Mode enregistrement :** Possibilité d'enregistrer une séquence et de la rejouer (sequencer simple).

### 9.7 Pièce 5 — La Salle de Mini-Jeux

**Audio :** Musique arcade 8-bit. Sons d'ordinateur/console.

**Gameplay :**
- Hub des mini-jeux créés par l'utilisateur via l'IDE NATHAN
- Nathan s'assoit à son poste et peut lancer un mini-jeu de la liste sur la carte SD
- Navigation dans la liste par audio (lecture du titre depuis les métadonnées)
- Retour au salon après fin d'un mini-jeu

### 9.8 Zone 6 — L'École (extérieur)

**Audio :** Sons de rue, bruits urbains, cour d'école, voix des camarades.

**Mécanique principale : Navigation avec le bâton**

C'est ici que le bâton d'aveugle est le contrôle primaire :
- **Joystick droit** : contrôle la direction du bâton (360°)
- Le raycast détecte obstacles, bordures de trottoir, portes
- Les **5 moteurs** donnent la direction du contact
- Le **son** de frappe change selon la surface

**Sous-zones de l'école :**
- Trajet aller (navigation en rue — obstacles mobiles : piétons)
- Cour de récréation (interactions sociales audio avec personnages)
- Salle de classe (mini-jeux pédagogiques : maths, mémoire, musique)

**Combats imaginaires :**
- Déclenchés optionnellement dans certaines zones
- Le bâton devient arme : mêmes contrôles, adversaires signalés par sons directionnels
- Détection de coup : le raycast touche un ennemi → impact fort + son
- L'ennemi riposte → vibration directionnelle + son d'attaque (le joueur peut parer)

### 9.9 Contrôles de déplacement global

| Contrôle | Action |
|---|---|
| Joystick gauche | Déplacement du personnage (marche/direction) |
| Joystick droit | Direction du bâton (mode bâton) / action contextuelle |
| Bouton A | Interagir / confirmer |
| Bouton B | Annuler / reculer |
| Bouton C | Menu contextuel de la pièce |
| Start | Menu pause |
| L1 | Mode bâton (activer/désactiver bâton) |
| R1 | Sprint |

### 9.10 Système de navigation sonore inter-pièces

Chaque pièce émet une **signature musicale** différente. Depuis le couloir, les musiques des pièces adjacentes sont audibles en spatialisation. Plus le joueur approche d'une porte, plus la musique de la pièce correspondante est forte et plus son positionnement directionnel est précis.

---

## 10. Système de mini-jeux

### 10.1 Architecture générale

```
┌─────────────────────┐         ┌─────────────────────────┐
│     PC / Mac        │  USB-C  │      MCU NATHAN         │
│                     │◄───────►│                         │
│  IDE NATHAN       │ (CDC)   │  MiniGameRunner         │
│  (développé         │         │  ┌──────────────────┐   │
│   séparément)       │         │  │  mini_game.py    │   │
│                     │         │  │                  │   │
│                     │         │  │  nathan.audio    │   │
│                     │         │  │  nathan.haptic   │   │
│                     │         │  │  nathan.input    │   │
│                     │         │  └──────────────────┘   │
└─────────────────────┘         └─────────────────────────┘
```

> L'IDE NATHAN est développé dans un dépôt séparé et sera intégré sous `ide/` une fois le protocole USB CDC (section 7.4) stabilisé. Le développement de l'IDE n'apparaît pas dans la planification de ce cahier des charges.

### 10.2 API MicroPython exposée aux mini-jeux

```python
import nathan

# Audio spatial
nathan.audio.play(sound_id: str, x: float, y: float, z: float = 0.0)
nathan.audio.stop(sound_id: str)
nathan.audio.set_ambient(sound_id: str)

# Haptique
nathan.haptic.pulse(motor: int, intensity: float, duration_ms: int)
  # motor: 0-4 (gauche à droite)
  # intensity: 0.0 à 1.0
nathan.haptic.sweep(direction: float, intensity: float)
  # direction: -1.0 (gauche) à 1.0 (droite)

# Entrées
x, y = nathan.input.joystick(id: int)  # id: 0=gauche, 1=droite
pressed = nathan.input.button(id: int)  # id: 0=A, 1=B, 2=C, 3=L1, 4=R1

# Contrôle du jeu
nathan.game.score(points: int)
nathan.game.end(success: bool)
nathan.game.set_title(title: str)

# Utilitaires
nathan.sleep_ms(ms: int)  # attente non bloquante
nathan.time_ms() -> int   # temps depuis démarrage
```

### 10.3 Format de mini-jeu

Le format est **directement inspiré** de l'architecture GlassBreaker existante (`game/menu.py`). Un mini-jeu est une **classe Python** avec métadonnées et méthodes standardisées.

```python
# Structure d'un mini-jeu NATHAN (MicroPython)
import nathan

META = {
    "title": "Mon Mini-Jeu",          # Lu à voix haute dans le hub
    "author": "Arthur",
    "description": "Un jeu de mémoire sonore"
}

class MonMiniJeu:
    def __init__(self):
        self.score = 0

    def setup(self):
        """Appelé une fois au démarrage."""
        nathan.audio.set_ambient("arcade_ambient.wav")
        nathan.audio.play("intro.wav", 0, 0, 0)

    def loop(self) -> bool:
        """
        Appelé à chaque frame.
        Retourne True pour continuer, False pour terminer.
        """
        x, y = nathan.input.joystick(0)
        if nathan.input.button(0):   # Bouton A
            nathan.audio.play("confirm.wav", 0, 0, 0)
            nathan.haptic.pulse(2, 0.8, 100)
            self.score += 1
        if self.score >= 10:
            nathan.game.end(success=True)
            return False
        return True

# Point d'entrée appelé par le MiniGameRunner
def create():
    return MonMiniJeu()
```

**Structure de fichiers sur la carte SD :**
```
/sd/minigames/
└── mon_mini_jeu/
    ├── main.py          # Fichier principal (contient META + classe)
    └── sounds/          # Sons du mini-jeu (WAV 16 bits, 44.1kHz, mono)
        ├── intro.wav
        ├── confirm.wav
        └── arcade_ambient.wav
```

---

## 11. Contraintes et risques

> Les contraintes détaillées, les hypothèses de travail et les plans de contingence sont documentés dans :
> - `CONTRAINTES.md` — 32 contraintes fixes (accessibilité, techniques, financières, réglementaires)
> - `HYPOTHESES.md` — 32 hypothèses de travail avec validation prévue et plan de contingence

### 11.1 Risques techniques principaux (résumé)

| Risque | Niveau | Mitigation |
|---|---|---|
| HRTF temps réel sur MCU embarqué | Critique | Benchmark PC d'abord → choix MCU adapté → fallbacks : filtres courts, moins de sources, DSP externe, stéréo simple |
| Autonomie batterie | Élevé | Gestion PWM moteurs, sleep Wi-Fi, batterie >= 2000 mAh |
| Intégration MicroPython dans le firmware | Moyen | Prototypage précoce, fallback vers Lua si incompatible |
| Ergonomie boîtier | Moyen | Itérations rapides en impression 3D, tests avec utilisateurs DV |
| Désynchronisation entre équipes | Élevé | Contrats d'interface gelés Phase 0, 3 SYNC, tests d'interface |
| Accessibilité de l'IDE | Moyen | Prototypage TTS/ARIA précoce, tests avec utilisateurs DV du groupe Discord |

### 11.2 Contraintes techniques reconnues

- Micro SD : Latence de lecture (~few ms) — les samples audio doivent être pré-chargés en RAM
- MicroPython : Vitesse d'exécution ~10-50x plus lente que C — les mini-jeux sont des jeux simples
- Le volume audio doit être géré par software (la plupart des DAC I2S n'ont pas de contrôle hardware)

---

## 12. Planification

> La planification détaillée (tâches, chronologie, chemins critiques parallèles, jalons de convergence,
> point de transition manette Xbox → manette NATHAN) est documentée dans `TACHES.md`.

### 12.1 Principe de planification

Le projet suit une approche **PC-first** avec 6 flux parallèles convergeant à des jalons clés :

1. **Game Engine** (ENG) — développé sur PC avec manette USB de substitution
2. **Audio HRTF** (AUD) — développé sur PC, porté après benchmark
3. **Hardware** (ELEC) — conçu après le choix du MCU basé sur les benchmarks
4. **Contenu de jeu** (JEU) — développé sur PC indépendamment du matériel
5. **IDE** (ENG) — développé en parallèle, intégré via USB CDC
6. **Communauté DV** — feedback continu via Discord tout au long du projet

### 12.2 Points de référence avec le code existant (GlassBreaker)

| Élément v2.0 | Référence dans GlassBreaker | Notes |
|---|---|---|
| InputMapper | `input/buttons.py` (ButtonManager) | Même pattern, étendre avec joysticks |
| SpatialAudioEngine | `output/audio.py` (AudioManager) | Logique de gestion WAV réutilisable |
| HapticEngine | `output/motors.py` (MotorManager) | Passer de 2 à 5 moteurs avec intensité |
| StorageProvider | `utils/memory.py` (MemoryManager) | Même principe, FAT32 sur SD |
| MiniGameRunner | `game/menu.py` (MenuExtension) | Même pattern classe + `run()` |

---

## 13. Budget

> Le budget détaillé et le suivi financier sont gérés dans `TACHES.md` (section Budget prévisionnel du RPC1).

**Contrainte budgétaire :** <= 500$ CAD pour le prototype (incluant réserve imprévus ~30%)
**Objectif de production :** < 100$ CAD par unité

**Tous les outils logiciels sont gratuits :** SDK du MCU (open-source), MicroPython (MIT), KiCAD, datasets HRTF (MIT KEMAR), Electron (MIT).

> Le coût exact du prototype dépend du MCU choisi. Une estimation par scénario MCU est réalisée dans le MIP (tâche MIP-03c).

---

## 14. Livrables

> La liste complète des livrables par session (académiques + techniques) et leur checklist
> se trouvent dans `TACHES.md`.

### 14.1 Livrables techniques

- Manette physique (PCB + boîtier + batterie) avec le MCU choisi
- Game engine fonctionnel (scènes, collisions, bâton, navigation, audio spatial)
- Module audio spatial (PCAudio + implémentation embarquée)
- Jeu "La Maison de Nathan" (>= 4 zones jouables)
- Système MicroPython (interpréteur + module `nathan` + sandbox + 2 mini-jeux)
- IDE de programmation accessible (éditeur + transfert USB + TTS)
- Documentation (API game engine, API MicroPython, protocole USB CDC)

### 14.2 Livrables académiques

- MIP, RPC1 (S6) — RPC2 (S7) — RLP (S8)
- RAE individuels (chaque session)
- Audits d'équipe et numériques
- Démonstration Expo MégaGÉNIALE (S8)

---

*Document vivant — à mettre à jour à chaque jalon atteint.*
*NATHAN Console — Open-source, accessible, pour tous.*

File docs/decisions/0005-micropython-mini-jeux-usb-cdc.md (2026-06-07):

# ADR-0005 — MicroPython pour les mini-jeux + transfert USB CDC

- **Statut :** Accepté
- **Date de la décision :** fondatrice du projet · **Consigné :** 2026-06-07 (rétroactif)
- **Décideurs :** ENG
- **Contexte projet :** modèle de programmation de la console
- **Liens :** [[specs/CAHIER-DES-CHARGES]], [[planning/TACHES]] (`S7-T11`, `S7-T12`, `S7-T15`, `S7-T16`), [[0006-ide-accessible-assistance-vocale]]

## Contexte et problème

La console doit permettre à la **communauté** — et à Nathan lui-même — de **créer et charger des mini-jeux facilement**, dans une optique d'accessibilité et d'open-source. Le modèle de programmation conditionne le firmware, l'IDE et le protocole de transfert.

## Options envisagées

- **A — Mini-jeux compilés en C/C++** flashés dans le firmware. *Contre :* cycle de développement lent, inaccessible aux non-experts, pas de chargement dynamique de jeux.
- **B — Interpréteur MicroPython embarqué (retenue) :** mini-jeux en `.py` chargés dynamiquement via **USB CDC** depuis l'IDE. *Pour :* itération rapide, accessible aux débutants, chargement sans reflash.

## Décision

Embarquer **MicroPython** pour les mini-jeux ; définir un **protocole USB CDC** (LIST / UPLOAD / DELETE / LOG) pour le transfert IDE ↔ console.

## Conséquences

- **+** Accessibilité et itération rapide ; chargement dynamique ; cohérent avec l'IDE (ADR-0006).
- **−** Coût RAM/CPU de l'interpréteur → **à intégrer au dimensionnement MCU** (ADR-0003) ; nécessite un gestionnaire de mini-jeux côté IDE (`S7-T16`).

## Suivi / quand re-questionner

Si le benchmark montre que MicroPython + HRTF ne tiennent pas ensemble sur le MCU retenu, réévaluer (sous-ensemble MicroPython, ou bytecode précompilé) via un nouvel ADR.

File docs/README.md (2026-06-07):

# Documentation NATHAN Console — Commencez ici

Bienvenue. Cette documentation est organisée pour qu'un **nouvel arrivant** (contributeur open-source ou nouveau membre d'équipe) puisse comprendre **quoi**, **pourquoi** et **quand**, dans cet ordre.

## Parcours de lecture recommandé

1. **[`/README.md`](../README.md)** — *quoi & pourquoi le projet existe* (l'histoire de NATHAN, la vision).
2. **[`architecture/`](./architecture/)** — *comment c'est construit* (diagrammes système et IDE).
3. **[`decisions/`](./decisions/README.md)** — *pourquoi c'est construit ainsi, et son évolution* (journal des ADR = la timeline des décisions).
4. **[`planning/TACHES.md`](./planning/TACHES.md)** — *quoi est fait / à faire et quand* (tâches, dates, dépendances, base du GANTT).
5. **[`specs/`](./specs/)** — *les exigences détaillées* (à consulter au besoin).

## Carte de la documentation

| Dossier | Contenu |
|---|---|
| [`decisions/`](./decisions/README.md) | **Journal des décisions (ADR)** — la traçabilité du *pourquoi* |
| [`planning/`](./planning/) | [`TACHES.md`](./planning/TACHES.md) (tâches/GANTT) · [`ESTIMATION.md`](./planning/ESTIMATION.md) (coûts, effort, 3 gammes MCU) |
| [`specs/`](./specs/) | [`CAHIER-DES-CHARGES.md`](./specs/CAHIER-DES-CHARGES.md) · [`REQUIS.md`](./specs/REQUIS.md) · [`BESOINS.md`](./specs/BESOINS.md) · [`CONTRAINTES.md`](./specs/CONTRAINTES.md) · [`HYPOTHESES.md`](./specs/HYPOTHESES.md) · [`CADRE-LOGIQUE.md`](./specs/CADRE-LOGIQUE.md) |
| [`architecture/`](./architecture/) | Diagrammes `.drawio` / `.mmd` (console et IDE) |

## Comment lire la « timeline et l'évolution »

- **Pourquoi (décisions) :** [`decisions/README.md`](./decisions/README.md) — index des ADR par date et statut. Une décision qui en remplace une autre est visible via les statuts *Remplace / Remplacé par*.
- **Livraisons (jalons) :** les **tags git** marquent les jalons (interfaces gelées, choix MCU, RPC1, RPC2, RLP). `git log --oneline --decorate` montre la chronologie.
- **Plan (futur) :** [`planning/TACHES.md`](./planning/TACHES.md) → Partie 3 (jalons de convergence, chemins critiques).
- **Détail d'un fichier :** `git log --follow <fichier>` (l'historique est préservé malgré la réorganisation).

## Traçabilité par identifiants

Tout est relié par des IDs stables :

```
Besoin → Requis (R-xx) / Contrainte (C-xx) / Hypothèse (H-xx)
       → Décision (ADR-xxxx)
       → Tâche (TACHES : ADM-/TECH-/S7-T/AUDHW-/…)
       → Code / PCB / diagramme
       → Commit (conventional commits) / tag de jalon
```

> Contribuer ? Voir **[`CONTRIBUTING.md`](../CONTRIBUTING.md)** — notamment « quand et comment écrire un ADR ».

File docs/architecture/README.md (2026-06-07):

# Diagrammes d'architecture

Diagrammes versionnés dans le repo (source synchronisée depuis le OneDrive de l'équipe) pour que le dépôt soit **auto-suffisant** pour un contributeur externe.

| Fichier | Décrit |
|---|---|
| `console.drawio` / `console.drawio.png` / `console.mmd` | Architecture **système** de la console (game engine, interfaces, blocs matériels) |
| `ide.drawio` / `ide.drawio.png` / `ide.mmd` | Architecture de l'**IDE** accessible |

**Ouvrir / éditer :**
- `.drawio` → [draw.io](https://app.diagrams.net/) ou l'extension *Draw.io Integration* de VS Code (le `.png` est un aperçu rapide, sans outil).
- `.mmd` → [Mermaid](https://mermaid.live/) ou un aperçu Markdown compatible Mermaid.

> Le diagramme système matérialise l'architecture **en contrats d'interface** décidée en [ADR-0001](../decisions/0001-architecture-pc-first-interfaces.md) (le game engine est agnostique du matériel). Toute évolution majeure de l'architecture doit s'accompagner d'un ADR.

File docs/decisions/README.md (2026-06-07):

# Journal des décisions (ADR)

> **Architecture Decision Records** — un fichier par décision d'architecture ou de conception.
> C'est la **frise chronologique** du *pourquoi* du projet : un nouvel arrivant lit ce journal pour comprendre comment NATHAN en est arrivé là, et comment les choix ont évolué.

## Comment ça marche

- **Un ADR = une décision**, dans un fichier `NNNN-titre.md` numéroté et daté.
- Un ADR **accepté est immuable**. Si une décision change, on **n'édite pas** l'ancien : on crée un nouvel ADR avec le statut *« Remplace ADR-XXXX »*, et l'ancien passe à *« Remplacé par ADR-YYYY »*. L'historique des virages reste lisible.
- Chaque ADR **lie** les besoins/requis/contraintes/hypothèses (`R-`, `C-`, `H-`, `E-`) et les tâches (`TACHES.md`) concernés.
- Voir [`CONTRIBUTING.md`](../../CONTRIBUTING.md) pour le gabarit et la procédure.

**Légende des statuts :** `Proposé` · `Accepté` · `Remplacé par ADR-XXXX` · `Déprécié`

## Index

| # | Décision | Statut | Date | Bloc concerné |
|---|---|---|---|---|
| [0001](./0001-architecture-pc-first-interfaces.md) | Architecture PC-first et contrats d'interface | ✅ Accepté | 2026-05-15 | Tous (fondation) |
| [0002](./0002-librairie-son-spatial-maison.md) | Librairie de son spatial **maison** (HRTF) | ✅ Accepté | 2026-06-07 | Audio |
| [0003](./0003-choix-mcu-benchmark-driven.md) | Choix du MCU **piloté par benchmark** (3 gammes) | ✅ Accepté | 2026-06-07 | PCB / Audio |
| [0004](./0004-option-repli-audio-fpga.md) | Option de repli audio **matérielle (FPGA/CPLD)** | ✅ Accepté *(activation conditionnelle)* | 2026-06-07 | Audio / PCB |
| [0005](./0005-micropython-mini-jeux-usb-cdc.md) | **MicroPython** pour les mini-jeux + USB CDC | ✅ Accepté | fondatrice | Game Engine / IDE |
| [0006](./0006-ide-accessible-assistance-vocale.md) | IDE accessible à **assistance vocale (TTS/STT + IA)** | ✅ Accepté *(orientation)* | 2026-06-07 | IDE |
| [0007](./0007-adoption-adr-structure-docs.md) | Adopter les **ADR** et la structure `docs/` | ✅ Accepté | 2026-06-07 | Gouvernance |

## Décisions à venir (futurs ADR)

Chaque tâche **« DÉCISION »** de `TACHES.md` produira un ADR au moment où elle est tranchée :

| Tâche | Décision attendue | Quand |
|---|---|---|
| `S7-T06` | **MCU effectivement retenu** (gamme A/B/C) | ~S7 sem 5 (fév. 2027) |
| `S7-T07` | **Chemin audio** : software pur / DSP externe / **FPGA-CPLD** (active ou non ADR-0004) | ~S7 sem 5 |
| `TECH-19` | **Stack de l'IDE** (Electron/React, Tauri, …) | S7 sem 1-2 |

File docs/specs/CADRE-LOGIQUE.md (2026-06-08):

# Cadre Logique — Projet NATHAN Console v2.0

**Date :** 2026-05-28
**Session :** PMC660 (S6, E2026)

---

## Niveau 4 — FINALITÉ

| Niveaux descriptifs | Indicateurs objectivement vérifiables | Moyens de vérification | Conditions critiques |
|---|---|---|---|
| **Offrir aux personnes non-voyantes une console de jeu accessible, open-source et abordable, où l'expérience est entièrement auditive et haptique.** | F1. Au moins 1 personne non-voyante (du groupe de testeurs recrutés via l'APHVE) complète une session de jeu de 15 min sans assistance extérieure, avec un score de satisfaction >= 3/5 sur l'immersion | Test utilisateur filmé avec protocole CER approuvé; questionnaire post-test avec échelle Likert 1-5 | Le partenaire APHVE reste disponible et recrute des testeurs DV; le CER approuve le protocole dans les délais |
| | F2. Coût de production unitaire estimé < 100$ CAD vs. solutions existantes (manettes adaptées > 300$) | BOM de production documenté; comparaison tarifaire avec 3 alternatives du marché | Prix des composants stables; pas de rupture d'approvisionnement |
| | F3. Code source, PCB et fichiers de boîtier publiés sous licence open-source | Dépôt GitHub public avec fichier LICENSE; Gerbers, STL et source accessibles | Aucune clause de confidentialité n'empêche la publication |

---

## Niveau 3 — OBJECTIFS DU PROJET

| Niveaux descriptifs | Indicateurs objectivement vérifiables | Moyens de vérification | Conditions critiques |
|---|---|---|---|
| **O1. Développer un game engine embarqué agnostique du matériel, avec audio spatial binaural HRTF fonctionnel au casque** | O1.1. Le même code de jeu fonctionne sans modification avec 2 sources d'entrées différentes (manette USB sur PC et manette finale) grâce aux interfaces abstraites | Démonstration du swap d'implémentation (GamepadMapper → NathanMapper) sans recompilation du game engine | Les interfaces définies en Phase 0 couvrent tous les cas d'usage; pas de changement majeur en cours de route |
| | O1.2. Audio spatial : 3/3 testeurs localisent une source sonore à +/- 30° au casque; >= 4 sources simultanées sans artefact; CPU coeur audio < 80% | Test perceptuel : sources à 0°, 90°, 180°, 270°, taux de localisation >= 80%; profiling CPU documenté | Le dataset HRTF open-source est compatible avec les contraintes mémoire du MCU choisi |
| | O1.3. Latence bout-en-bout (action → son au casque) < 50 ms; latence haptique < 100 ms | Mesure instrumentée (oscilloscope ou timer haute résolution) | Le MCU choisi a la puissance suffisante (validée par benchmark PC préalable) |
| **O2. Concevoir et fabriquer une manette de jeu ergonomique avec le microcontrôleur choisi selon les besoins mesurés** | O2.1. Microcontrôleur choisi sur la base d'un document de justification quantitatif (CPU, RAM, I2S, USB, ADC) comparant >= 3 candidats | Document de justification avec benchmark PC comme baseline; matrice de décision pondérée | Le benchmark PC est réalisé avant le choix (sem 12-14) |
| | O2.2. PCB fabriqué et fonctionnel : 0 court-circuit, tensions conformes (3.3V +/- 5%), tous les sous-systèmes testés individuellement | Tests électriques documentés (continuité, tensions à l'oscilloscope); firmware boot réussi | Le fabricant livre le PCB dans les 2-3 semaines |
| | O2.3. Boîtier ergonomique : 3/3 testeurs confortables pendant 30 min; 5/5 contrôles identifiés au toucher les yeux bandés; autonomie >= 4h | Test d'ergonomie avec protocole; test d'autonomie chronométré | Imprimante 3D disponible; batterie de capacité suffisante disponible |
| **O3. Créer "La Maison de Nathan", un jeu entièrement audio-haptique avec >= 4 zones jouables** | O3.1. >= 4 zones (Salon, Cuisine, Chambre, Salle de Musique) jouables avec ambiance distincte + >= 2 interactions par zone | Démonstration devant le superviseur : parcours des 4 zones au casque avec checklist | Les assets audio (>= 50 sons, >= 10 narrations) sont disponibles à temps |
| | O3.2. Navigation inter-pièces : joueur aux yeux bandés identifie >= 3 pièces par leur signature musicale directionnelle | Test documenté : joueur départ au Salon, identifie les directions | L'audio spatial (O1) est fonctionnel avant l'intégration du jeu (sem 10) |
| | O3.3. Tutoriel intégré : nouveau joueur comprend les contrôles en < 5 min | Test avec 2 nouveaux joueurs; temps mesuré | Narration vocale enregistrée à temps |
| **O4. Permettre la programmation de mini-jeux MicroPython exécutés depuis une carte SD** | O4.1. Mini-jeu de < 50 lignes utilisant l'API `nathan.*` (audio, haptic, input) fonctionne sur la console | Démonstration : écriture, upload USB, exécution sur console | L'interpréteur MicroPython s'intègre dans le firmware sans conflit |
| | O4.2. >= 2 mini-jeux d'exemple livrés et jouables depuis le hub | Mini-jeux jouables lors de la démo finale | Mini-jeux testés avant la livraison |

---

## Niveau 2 — EXTRANTS

| Niveaux descriptifs | Indicateurs objectivement vérifiables | Moyens de vérification | Conditions critiques |
|---|---|---|---|
| **E1. Contrats d'interface gelés (5 contrats : Input, Audio, Haptic, Storage, MiniGame)** | 5 fichiers `.h` validés et signés par les équipes à la semaine 2; chaque contrat a >= 2 implémentations fonctionnelles | Revue croisée; tests unitaires passent avec chaque implémentation | Toutes les équipes participent à la Phase 0 |
| **E2. Game engine fonctionnel sur PC (scènes, collisions, bâton, navigation, audio spatial)** | Session de jeu de 15 min sur PC sans crash ni fuite mémoire; heap libre stable après 10 transitions de scène | Démonstration PC au SYNC 2 (sem 14); rapport de stabilité | PCAudio (E4) prêt avant la sem 10 |
| **E3. Rapport de benchmark PC** | Document quantitatif : CPU par source audio, RAM totale, taille buffers, latence mesurée; comparaison avec >= 3 MCU candidats | Rapport écrit avec mesures; validé par l'équipe AUD et ENG | Outils de profiling disponibles |
| **E4. Module audio spatial PCAudio** | Toutes les fonctions du contrat SpatialAudioEngine implémentées; 4+ sources; taux de localisation >= 80% (test perceptuel 3 testeurs) | Démo audio au SYNC 1 (sem 6); test perceptuel documenté | Bibliothèque audio PC (miniaudio ou autre) fonctionnelle |
| **E5. Module audio embarqué** | Audio spatial fonctionnel sur MCU choisi; même qualité perceptuelle que PCAudio (test A/B); latence < 20 ms | Démo au SYNC 3 (sem 22); rapport benchmark embarqué | Portage HRTF faisable en software pur (ou DSP ajouté au budget) |
| **E6. Manette physique (PCB + boîtier + batterie)** | PCB fonctionnel (0 erreur ERC/DRC); boîtier imprimé; assemblage complet; test d'ergonomie passé | Photos assemblage; captures ERC/DRC; rapport tests électriques | Fabricant PCB livre à temps; imprimante 3D disponible |
| **E7. Jeu "La Maison de Nathan" (code + assets)** | >= 50 WAV 16bit/44.1kHz; >= 4 zones avec interactions; >= 10 clips narration; >= 6 ambiances musicales | Inventaire des assets; test de chaque zone avec checklist | Microphone/logiciel d'enregistrement disponible |
| **E8. Intégration MicroPython + module `nathan` + 2 mini-jeux** | Module `nathan` expose >= 10 fonctions API testées unitairement; sandbox vérifié; 2 mini-jeux jouables | Tests unitaires; démo des mini-jeux | `micropython-embed` compatible avec le MCU choisi |
| **E9. IDE de programmation accessible (5 couches : UX accessible, Édition, Assistant IA, Déploiement, Matériel)** | IDE fonctionnel : éditeur MicroPython avec coloration + linter + TTS + screen reader + transfert USB CDC + logs en temps réel + gestionnaire de mini-jeux; cycle écrire→transférer→jouer < 1 min | Démonstration : écriture d'un mini-jeu dans l'IDE, upload, exécution sur console; test d'accessibilité avec lecteur d'écran et 1 utilisateur DV du groupe Discord | Stack technologique maîtrisée; Web Serial API ou serialport npm fonctionnel; TTS français de qualité suffisante |
| **E10. Documentation + BOM** | README à jour; API game engine documentée (>= 15 fonctions); API MicroPython (>= 10 fonctions); BOM avec prix réels <= 500$ | Documents dans le dépôt; BOM comparé aux factures | Temps alloué à la documentation |

---

## Niveau 1 — INTRANTS

| Niveaux descriptifs | Indicateurs objectivement vérifiables | Moyens de vérification | Conditions critiques |
|---|---|---|---|
| **I1. Équipe de 8 étudiants (GE + GI)** | 8 membres actifs; 135h/personne en S6 (1080h équipe), 540h/personne sur les 3 sessions; >= 1 GE, >= 1 GI signal/audio, >= 2 GI firmware | Feuilles de temps hebdomadaires; matrice de compétences | Pas d'abandon; membres inscrits à PMC660 |
| **I2. Budget <= 500$ CAD** | Achats tracés; réserve imprévus 30% (100$) planifiée | Tableau de suivi financier; factures conservées | Financement confirmé (autofinancement ou partenaire) |
| **I3. Matériel de développement initial** | >= 2 manettes USB (PS4/Xbox); casque stéréo; achetés avant sem 3 | Confirmation de réception | Livraison <= 2 semaines |
| **I4. Matériel MCU et prototypage** | DevKit du MCU choisi + DAC + moteurs + joysticks + batterie; achetés après le choix du MCU (S7, après benchmark) | Confirmation de commande post-SYNC 2 | Composants disponibles chez les fournisseurs |
| **I5. Outils logiciels** | Toolchain du MCU installée sur >= 2 postes; KiCAD; SolidWorks (licence UdeS); bibliothèque audio PC | Build réussi sur 2 postes | Licences actives; machines suffisantes |
| **I6. Locaux et équipement** | Accès laboratoire UdeS (soudure, oscilloscope); imprimante 3D | Réservation confirmée; formation sécurité complétée | Disponibilité Faculté de génie |
| **I7. Temps : 26 semaines, 3 sessions** | SYNC 1 (sem 6), SYNC 2 (sem 14), SYNC 3 (sem 22); contrats gelés sem 2 | Gantt/tableau de planification; PV des SYNC | Chemin critique respecté (benchmark → choix MCU → portage) |
| **I8. Partenaire, communauté DV et approbation éthique** | >= 2 rencontres avec l'APHVE; serveur Discord créé; >= 5 utilisateurs DV recrutés (par l'équipe + APHVE); >= 3 consultations documentées; formulaire CER soumis >= 4 sem avant test; réponse CER obtenue | PV rencontres; liste des membres Discord; logs des consultations; email CER; lettre d'approbation/dispense | APHVE disponible; Discord accessible aux personnes DV; CER traite dans les délais |

---

## Lecture causale (de bas en haut)

1. **Si** les intrants sont disponibles **et** les conditions critiques du niveau 1 sont respectées,
   **alors** les extrants seront produits.

2. **Si** les extrants sont produits **et** les conditions critiques du niveau 2 sont respectées,
   **alors** les objectifs seront atteints.

3. **Si** les objectifs sont atteints **et** les conditions critiques du niveau 3 sont respectées,
   **alors** la finalité sera réalisée.

---

*Document vivant — à réviser à chaque coaching et SYNC.*

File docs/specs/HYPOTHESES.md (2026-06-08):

# Hypothèses de Travail — Projet NATHAN Console v2.0

**Date :** 2026-05-28
**Session :** PMC660 (S6, E2026)

> Les hypothèses de travail sont des **suppositions acceptées comme vraies** pour la planification,
> mais qui **pourraient s'avérer fausses** et nécessiter un ajustement.
> Chaque hypothèse est suivie en continu : si elle est invalidée, le plan de contingence s'active.
> Voir `CONTRAINTES.md` pour les limitations fixes non négociables.

---

## Légende

| Statut | Description |
|---|---|
| **Acceptée** | Validée par observation ou preuve |
| **Active** | En vigueur, pas encore validée ni invalidée |
| **À valider** | Doit être vérifiée à une date précise |
| **Invalidée** | S'est avérée fausse : contingence activée |

---

## 1. Partenaire et utilisateurs DV

| ID | Hypothèse | Statut | Validation prévue | Plan de contingence |
|----|---|---|---|---|
| H-01 | **Engagement APHVE** : l'APHVE accepte de s'engager comme partenaire officiel et de signer la convention SARIC | Active | Présentation du MIP à l'APHVE (sem 4-5) | Chercher un autre organisme DV (IRDPQ, INLB) ou poursuivre sans partenaire formel |
| H-02 | **Recrutement testeurs** : l'APHVE aide à recruter >= 5 personnes DV pour tester/consulter tout au long du projet | Active | Présentation du MIP à l'APHVE (sem 4-5) | Recruter via d'autres organismes DV ou la communauté Discord du projet |
| H-03 | **Délai CER** : le CER approuve le protocole DV en 1-2 semaines (pas de CER complet requis) | Active | Soumission du formulaire d'avis (>= 4 sem avant le test) | Si CER complet requis : prévoir 4-8 semaines de plus. Soumettre dès S7. |
| H-04 | **Pas de clause de confidentialité bloquante** : l'APHVE n'empêche pas la publication open-source | Active | Négociation de la convention SARIC | Négocier une exclusion pour le code et les fichiers de conception. En dernier recours, retarder la publication. |
| H-05 | **Discord accessible** : un serveur Discord est utilisable par les personnes DV (compatible lecteur d'écran) | Active | Création du serveur et test avec 1-2 utilisateurs DV (sem 5-6) | Utiliser un canal alternatif (email, WhatsApp, Telegram) si Discord n'est pas accessible |
| H-06 | **Engagement durable du groupe** : les membres DV répondent à >= 3 consultations sur la durée du projet | Active | Suivi de l'engagement tout au long du projet | Recruter de nouveaux membres en cas de départs; proposer des incitatifs (accès prioritaire au prototype) |

---

## 2. Audio HRTF

| ID | Hypothèse | Statut | Validation prévue | Plan de contingence |
|----|---|---|---|---|
| H-07 | **HRTF faisable sur MCU** : le rendu HRTF temps réel (>= 4 sources) tient sur un microcontrôleur de la gamme visée | À valider | Benchmark PC (S7) → estimation → benchmark sur le MCU choisi (S7) | Fallbacks : filtres courts (128 vs 512 samples); 2-3 sources max; DSP externe (~30$); stéréo simple sans HRTF |
| H-08 | **Qualité du dataset HRTF** : un dataset open-source (MIT KEMAR, CIPIC, SOFA) donne une localisation suffisante (erreur < 30°) | À valider | Tests perceptuels au casque (S6-S7) | Tester plusieurs datasets; envisager des HRTF individualisées ou accepter une précision moindre |
| H-09 | **HRTF en mémoire** : les tables tiennent en <= 1.5 MB RAM en laissant de la marge pour le moteur et les buffers | À valider | Mesure de la taille mémoire pendant le prototypage PC | Compresser les HRTF (moins de positions) ou réduire la résolution |
| H-10 | **Bibliothèque audio portable** : la bibliothèque PC choisie n'introduit pas de dépendance bloquante pour le portage | À valider | Choix de la bibliothèque (S6) | Écrire un wrapper minimal; le contrat SpatialAudioEngine isole déjà le moteur de l'implémentation |

---

## 3. Firmware et intégration

| ID | Hypothèse | Statut | Validation prévue | Plan de contingence |
|----|---|---|---|---|
| H-11 | **MicroPython intégrable** : l'interpréteur s'intègre dans le firmware C/C++ sans conflit mémoire ni scheduler | À valider | Prototypage d'intégration (S7) | Utiliser Lua (plus léger, mieux intégré en C) et adapter le format de mini-jeu |
| H-12 | **Interfaces suffisantes** : les interfaces de Phase 0 couvrent tous les cas d'usage du développement | Active | Tout au long du dev; validation formelle au SYNC 1 (sem 6) | Modifier l'interface avec accord des 2 équipes; l'architecture limite l'impact |
| H-13 | **GamepadMapper fidèle** : la manette PS4/Xbox est un substitut suffisant malgré l'absence de 5 moteurs | Active | Premiers tests de jeu sur PC (S6) | Mode de simulation haptique avancé (logs d'intensité) ou gamepad à retour haptique plus riche |
| H-14 | **Portage sans réécriture majeure** : le passage du PC au MCU se limite aux implémentations d'interface | À valider | Portage effectif (S8) | Prévoir du temps supplémentaire; l'architecture en blocs isole les changements |

---

## 4. Matériel

| ID | Hypothèse | Statut | Validation prévue | Plan de contingence |
|----|---|---|---|---|
| H-15 | **MCU adéquat disponible** : un MCU satisfait CPU, RAM, I2S, USB OTG, >= 4 ADC, >= 5 PWM pour < 15$ | À valider | Analyse des candidats MCU (S6-S7) | Relâcher une contrainte (USB ou PWM via puce externe); accepter un coût unitaire plus élevé |
| H-16 | **Livraison PCB <= 3 semaines** : le fabricant (JLCPCB/PCBWay) respecte ce délai | Active | À chaque commande de PCB | Commander plus tôt; garder un plan de test breadboard comme repli temporaire |
| H-17 | **Moteurs ERM assez rapides** : temps de réponse < 100 ms pour un feedback perceptible | À valider | Tests sur breadboard (S7) | Passer à des moteurs LRA avec driver DRV2605L (plus rapides, ~5$/unité) |
| H-18 | **Autonomie suffisante** : la batterie LiPo (>= 2000 mAh) donne >= 4h en usage typique | À valider | Test d'autonomie sur prototype assemblé (S8) | Augmenter la capacité (3000+ mAh); optimiser la consommation (sleep Wi-Fi, PWM réduit) |
| H-19 | **Boîtier 3D solide et ergonomique** : utilisable 30+ min sans inconfort | À valider | Test d'ergonomie (S8) | Itérer le design; passer au PETG (plus résistant); ajouter du rembourrage |

---

## 5. IDE

| ID | Hypothèse | Statut | Validation prévue | Plan de contingence |
|----|---|---|---|---|
| H-20 | **Stack IDE adéquat** : la stack choisie permet un IDE accessible (TTS, ARIA, clavier) dans les délais | À valider | Prototype IDE (S7) | Réduire le périmètre (éditeur + transfert USB); fallback vers VSCode + extension custom |
| H-21 | **TTS français suffisant** : la Web Speech API (ou équivalent) vocalise correctement code et diagnostics | À valider | Tests TTS lors du prototype IDE (S7) | Bibliothèque TTS tierce (eSpeak, pico2wave) ou service cloud (Google TTS) |
| H-22 | **USB série fiable** : la communication (Web Serial ou serialport npm) fonctionne de façon fiable IDE → console | À valider | Tests d'intégration IDE-console (S7) | Script de transfert en ligne de commande comme repli |
| H-23 | **Assistant IA faisable** : l'intégration d'un LLM dans l'IDE tient dans le périmètre | À valider | Prototypage en S7 (si temps disponible) | Reporter l'IA en post-livraison; l'IDE reste fonctionnel sans IA |

---

## 6. Ressources

| ID | Hypothèse | Statut | Validation prévue | Plan de contingence |
|----|---|---|---|---|
| H-24 | **Équipe stable** : les 8 membres restent actifs, dont >= 1 GE et >= 1 spécialisé signal/audio | Active | Formation des équipes (S6 sem 1) | Redistribuer les responsabilités; confier le PCB à un GI expérimenté si pas de GE |
| H-25 | **Laboratoires accessibles** : labos de la Faculté disponibles (l'équipe a ses propres imprimantes 3D) | Active | Réservation des locaux (S7-S8) | Réserver tôt; utiliser les imprimantes de l'équipe comme solution principale |
| H-26 | **Composants en stock** : disponibles chez les fournisseurs (DigiKey, Mouser, Amazon), livrables en <= 2 semaines | Active | À chaque commande | Commander en avance; identifier des composants alternatifs (second source) |
| H-27 | **Budget suffisant** : 500$ couvre le prototype complet (imprévus inclus) | Active | Suivi financier continu | Réduire le périmètre (3 moteurs au lieu de 5); financement additionnel; composants récupérés |
| H-28 | **Production audio interne** : l'équipe peut produire les assets (enregistrements, création) et compléter avec du CC0 | Active | Production des sons (S6) | Sourcer les sons manquants sur Freesound.org (CC0); outils de synthèse sonore |

---

## 7. Gestion

| ID | Hypothèse | Statut | Validation prévue | Plan de contingence |
|----|---|---|---|---|
| H-29 | **Implication des membres** : chacun investit ~135h/session et respecte le contrat d'équipe | Active | Suivi hebdomadaire des heures | Mécanisme PME (évaluation par les pairs); discussion avec le superviseur; redistribution |
| H-30 | **Méthode de gestion adaptée** : la méthode choisie (traditionnelle, agile, hybride) convient au projet | Active | Évaluation après le SYNC 1 (sem 6) | Ajuster ou changer de méthode en cours de projet |
| H-31 | **Feedbacks intégrables** : les retours du coaching n'exigent pas de remise en question fondamentale | Active | Après chaque coaching | L'architecture en interfaces absorbe la plupart des changements; sinon réévaluer le périmètre |
| H-32 | **Convention SARIC dans les délais** : la convention de partenariat se conclut sans bloquer le projet | Active | Suivi du dossier SARIC (S6-S7) | Avancer le développement en parallèle; relancer la coordination PMC en cas de retard |

---

## Suivi des hypothèses

Le statut de chaque hypothèse est revu aux points de synchronisation :

| Moment | Hypothèses à valider en priorité |
|---|---|
| **SYNC 1** (sem 6) | H-01 (partenaire), H-02 (recrutement), H-05 (Discord), H-08 (qualité HRTF), H-12 (interfaces), H-13 (GamepadMapper), H-24 (équipe) |
| **SYNC 2** (sem 14) | H-07 (HRTF embarqué), H-09 (mémoire HRTF), H-10 (bibliothèque audio), H-11 (MicroPython), H-15 (MCU), H-20 (stack IDE), H-21 (TTS) |
| **SYNC 3** (sem 22) | H-06 (engagement DV), H-14 (portage), H-16 (livraison PCB), H-17 (moteurs ERM), H-18 (autonomie), H-19 (boîtier), H-22 (USB série IDE) |

---

*Document vivant — mettre à jour le statut de chaque hypothèse dès qu'une information nouvelle est disponible.*

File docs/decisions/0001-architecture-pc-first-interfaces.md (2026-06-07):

# ADR-0001 — Architecture PC-first et contrats d'interface

- **Statut :** Accepté
- **Date de la décision :** 2026-05-15 (gel des interfaces) · **Consigné :** 2026-06-07 (rétroactif)
- **Décideurs :** ENG, AUD, ELEC
- **Contexte projet :** S6, jalon « interfaces gelées »
- **Liens :** C-05 (engine agnostique du matériel), C-06 (PC-first), R-31, [[planning/TACHES]] Bloc 0 (`TECH-01`, `TECH-02`), [[0003-choix-mcu-benchmark-driven]], [[0004-option-repli-audio-fpga]]

## Contexte et problème

La console est embarquée mais **le microcontrôleur n'est pas encore choisi** (voir ADR-0003). L'équipe est pluridisciplinaire (logiciel / audio / électronique) et doit avancer **en parallèle**. Si le jeu et le moteur sont couplés directement au matériel, **rien ne peut progresser avant le choix du MCU** — ce qui bloquerait tout le projet et empêcherait de tester tôt.

## Options envisagées

- **A — Développer directement sur le MCU** choisi tôt. *Contre :* bloque tout jusqu'au choix MCU, difficile à tester, décision matérielle prématurée et risquée.
- **B — Architecture en contrats d'interface (retenue) :** définir 5 contrats (Input, SpatialAudio, Haptic, Storage, MiniGame), avec des implémentations **PC d'abord**, **embarquées ensuite** (simple *swap* d'implémentation). *Pour :* développement parallèle, tests sur PC, choix MCU différé au benchmark. *Contre :* discipline de gel des interfaces requise.

## Décision

Adopter l'architecture **PC-first** : 5 contrats d'interface gelés en début de S6 (`TECH-02`). **Le game engine ne sait jamais s'il parle à une manette Xbox ou à la manette NATHAN.** Phase PC (S6-S7) → swap embarqué (S8).

## Conséquences

- **+** Développement parallèle sur tous les blocs ; stratégie benchmark-driven possible (ADR-0003) ; absorbe les implémentations de repli (`EmbeddedAudio`, et `HardwareAudio` FPGA — ADR-0004) sans refonte.
- **−** Tout changement d'interface après le gel exige l'accord des 2 équipes ; léger surcoût d'abstraction.

## Suivi / quand re-questionner

Si une interface se révèle inadaptée au portage embarqué (S7-S8), ouvrir un nouvel ADR la remplaçant plutôt que de modifier celui-ci.

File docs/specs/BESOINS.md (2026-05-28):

# Besoins — Projet NATHAN Console v2.0

**Date :** 2026-05-28
**Session :** PMC660 (S6, E2026)

> Les besoins décrivent **ce que le mandataire et les utilisateurs attendent** du produit.
> Ils expriment le **pourquoi** : les problèmes à résoudre et les résultats souhaités.
> Voir `REQUIS.md` (spécifications mesurables), `CONTRAINTES.md` (limites), `HYPOTHESES.md` (suppositions).

---

## 1. Besoins du mandataire (APHVE)

| ID | Besoin | Contexte | Requis liés |
|----|---|---|---|
| B-01 | **Aucune console dédiée n'existe** : un produit conçu dès le départ pour un utilisateur qui ne voit pas | Les solutions existantes sont des adaptations partielles de consoles visuelles (manettes adaptées > 300$). L'APHVE confirme ce besoin non comblé dans sa communauté. | R-01, R-02, R-14 |
| B-02 | **Immersion sonore 3D** : localiser les objets, murs et personnages uniquement par le son au casque | Le son spatial remplace la vue pour comprendre l'environnement de jeu. | R-01, R-02, R-04 |
| B-03 | **Retour tactile directionnel** : sentir la direction des contacts et obstacles par vibrations, comme un bâton d'aveugle | Le toucher complète le son pour percevoir l'espace immédiat. | R-03, R-05, R-22 |
| B-04 | **Jouer de la musique** : guitare, batterie de manière intuitive | Répond à l'intérêt des personnes DV pour la musique comme mode d'expression privilégié. | R-10 |
| B-05 | **Produit abordable** : accessible aux personnes et organismes desservant les personnes DV | Comparé aux solutions existantes (manettes adaptées, équipements spécialisés > 300$). | R-60 |
| B-06 | **Open-source** : reproductible, modifiable et améliorable par d'autres | Permet la pérennité et la diffusion au-delà du cadre académique. | R-61 |
| B-07 | **Validation par les utilisateurs DV** : tester avec un groupe recruté via l'APHVE | S'assurer que le produit répond réellement aux besoins du public cible. | R-56, R-58 |

---

## 2. Besoins des utilisateurs finaux (joueurs non-voyants)

### 2.1 Expérience de jeu

| ID | Besoin | Contexte | Requis liés |
|----|---|---|---|
| B-08 | **Jouer sans aide extérieure** : prendre la console, l'allumer et jouer de façon autonome | L'autonomie est fondamentale pour les personnes DV. Dépendre d'un tiers annule le plaisir. | R-01, R-06 |
| B-09 | **Comprendre les contrôles rapidement** : apprendre sans lire de manuel | L'apprentissage doit être entièrement audio, via un tutoriel vocal intégré. | R-06 |
| B-10 | **Se repérer dans l'espace** : savoir où on est et dans quelle direction aller, sans carte visuelle | Le son spatial 3D et le bâton virtuel remplacent la carte et la vision. | R-02, R-04, R-05 |
| B-11 | **Distinguer les zones** : chaque lieu a une identité sonore propre | Comme dans la vie réelle, une personne aveugle se repère par les sons ambiants. | R-09 |
| B-12 | **Feedback immédiat** : son + vibration à chaque action, sans délai perceptible | Sans retour visuel, un délai crée de l'incertitude et de la frustration. | R-15, R-16 |
| B-13 | **Confort prolongé** : jouer 30+ min sans fatigue des mains ni inconfort | La manette doit être ergonomique, légère et son autonomie ne doit pas couper une session. | R-24, R-27 |

### 2.2 Accessibilité physique

| ID | Besoin | Contexte | Requis liés |
|----|---|---|---|
| B-14 | **Identifier chaque contrôle au toucher** : savoir instantanément quel bouton ou joystick on touche | Les contrôles doivent avoir formes, tailles ou textures distinctes. | R-28 |
| B-15 | **Brancher le casque facilement** : port jack 3.5mm localisable au toucher | Un port mal placé crée une frustration disproportionnée sans la vue. | R-23 |
| B-16 | **Connaître l'état de la console** : allumée/éteinte/en charge via un feedback non visuel | Les LEDs de statut sont inutiles; le feedback doit être sonore ou haptique. | R-01 |

---

## 3. Besoins des utilisateurs créateurs (programmeurs de mini-jeux)

| ID | Besoin | Contexte | Requis liés |
|----|---|---|---|
| B-17 | **Programmer sans connaissances avancées** : langage simple et API intuitive | Le public cible inclut des personnes DV apprenant la programmation; MicroPython pour sa simplicité. | R-07, R-35 |
| B-18 | **IDE entièrement accessible** : TTS, lecteur d'écran, clavier, sans éditeur tiers non adapté | Les IDE standards ne sont pas optimisés pour une utilisation sans vision. | R-36 à R-46 |
| B-19 | **Aide pendant la programmation** : diagnostics vocaux, modèles de code, assistant IA | Un débutant DV a besoin d'un feedback immédiat et vocal sur ses erreurs. | R-42, R-43, R-47 |
| B-20 | **Transfert facile** : envoyer un mini-jeu sur la console sans compilation ni flashage | Un simple transfert de fichier .py via USB suffit. | R-49, R-52 |
| B-21 | **Test rapide** : cycle écrire → transférer → jouer court (< 1 min) | Un cycle long décourage les créateurs, surtout les débutants. | R-52 |
| B-22 | **Logs en temps réel** : voir les logs de la console dans l'IDE pour déboguer | Sans feedback visuel du jeu, les logs sont le seul moyen de comprendre l'exécution. | R-50 |
| B-23 | **API claire et documentée** : son spatial, haptique, entrées | Les fonctions `nathan.*` doivent être auto-explicatives. | R-35 |

---

## 4. Besoins de l'équipe de projet

| ID | Besoin | Contexte | Requis liés |
|----|---|---|---|
| B-24 | **Travailler en parallèle** : pas de blocage entre les équipes (ELEC, ENG, AUD, JEU) | Avec 4 sous-équipes sur 3 sessions, le blocage croisé est le danger principal; les interfaces le résolvent. | R-31, R-32, R-33 |
| B-25 | **Développer sans attendre le matériel** : jeu jouable sur PC dès S6 avec manette USB | Le matériel ne sera prêt qu'en S8; le développement ne doit pas être bloqué. | R-31 |
| B-26 | **IDE intégré au projet** : développé par l'équipe, accessible et fonctionnel à la livraison | L'IDE est indissociable de l'expérience NATHAN (programmation des mini-jeux). | R-36, R-49 |
| B-27 | **Choisir le MCU sur des données concrètes** : pas sur des spéculations | Le benchmark PC mesure les besoins réels avant de sélectionner le composant. | R-30 |
| B-28 | **Respecter le cadre académique** : produire les livrables PMC dans les délais | Le projet est autant un exercice de gestion qu'un défi technique. | R-62 |
| B-29 | **Démontrer à l'Expo MégaGÉNIALE** : présentation convaincante et accessible au public | L'Expo est le point culminant; le prototype doit être fonctionnel et présentable. | R-63 |

---

## 5. Besoins de la communauté et de la société

| ID | Besoin | Contexte | Requis liés |
|----|---|---|---|
| B-30 | **Démocratiser le jeu vidéo** : pour les personnes ayant une déficience visuelle | Le jeu vidéo est un loisir universel dont les personnes DV sont largement exclues. | Finalité F1 (cadre logique) |
| B-31 | **Impliquer les utilisateurs DV en continu** : pas seulement aux tests finaux | Le feedback continu (via Discord) valide les choix de conception au fur et à mesure. | R-55, R-56 |
| B-32 | **Plateforme pédagogique** : apprendre la programmation via la création de mini-jeux | La programmation est un outil d'autonomisation pour les personnes DV. | R-07 |
| B-33 | **Contribution communautaire** : survie du projet au-delà du cadre académique | Un projet open-source documenté peut être repris par d'autres institutions. | R-61 |

---

## Traçabilité Besoins → Requis

| Besoin | Requis associés |
|---|---|
| B-01, B-02 | R-01, R-02, R-04, R-14 |
| B-03 | R-03, R-05, R-22 |
| B-04 | R-10 |
| B-05 | R-60 |
| B-06, B-33 | R-61 |
| B-07, B-31 | R-55, R-56, R-58 |
| B-08, B-09 | R-01, R-06 |
| B-10 | R-02, R-04, R-05 |
| B-11 | R-09 |
| B-12 | R-15, R-16 |
| B-13 | R-24, R-27 |
| B-14, B-15, B-16 | R-23, R-28 |
| B-17, B-23 | R-07, R-35 |
| B-18, B-19, B-26 | R-36 à R-52 |
| B-20, B-21, B-22 | R-49, R-50, R-52 |
| B-24, B-25 | R-31, R-32, R-33 |
| B-27 | R-30 |
| B-28 | R-62 |
| B-29 | R-63 |
| B-32 | R-07 |

---

*Document vivant — à réviser après chaque rencontre avec le partenaire pour s'assurer que les besoins reflètent toujours les attentes réelles.*

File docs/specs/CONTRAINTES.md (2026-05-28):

# Contraintes — Projet NATHAN Console v2.0

**Date :** 2026-05-28
**Session :** PMC660 (S6, E2026)

> Les contraintes sont des **limitations fixes** que le projet doit respecter.
> Elles ne sont pas négociables : elles encadrent l'espace de solution.
> Voir `HYPOTHESES.md` pour les suppositions de travail qui, elles, pourraient changer.

---

## 1. Contraintes d'accessibilité

| ID | Contrainte | Justification |
|----|---|---|
| C-01 | **Aucun retour visuel** : le système fonctionne sans écran ni LED nécessaire au gameplay | Le public cible est non-voyant. Tout feedback visuel serait inutile et exclurait l'utilisateur principal. |
| C-02 | **Casque stéréo uniquement** : pas de haut-parleurs | L'audio binaural (HRTF) nécessite un casque; des haut-parleurs détruiraient l'illusion directionnelle. |
| C-03 | **Contrôles différenciables au toucher** : sans indication visuelle | L'utilisateur ne peut lire d'étiquettes ni voir les couleurs. Forme, taille et position doivent suffire. |
| C-04 | **Menus navigables au son** : toutes les interactions exclusivement par l'audio | Aucun menu textuel ne peut être affiché. Annonces vocales, signatures musicales et sons d'interface. |

---

## 2. Contraintes techniques

| ID | Contrainte | Justification |
|----|---|---|
| C-05 | **Game engine agnostique** : interfaces abstraites (contrats) entre le moteur et le matériel | Permet le développement parallèle sur PC et le portage ultérieur sans réécriture. Stratégie fondamentale du projet. |
| C-06 | **Développement PC-first** : développer sur PC avant tout portage embarqué | Le choix du MCU dépend des besoins mesurés par benchmark. Développer sur PC évite d'être bloqué par le matériel. |
| C-07 | **Choix du MCU basé sur benchmark** : décision quantitative (CPU, RAM, I/O) mesurée pendant le dev PC | Choisir un MCU avant de connaître les besoins risquerait de sélectionner un composant inadéquat. |
| C-08 | **Format audio standard** : WAV 16 bits, 44.1 kHz, mono (effets) ou stéréo (ambiances) | Compatible avec les pipelines audio embarqués. Le mono est requis pour la spatialisation HRTF. |
| C-09 | **Mini-jeux en MicroPython** : pas en C/C++ | MicroPython est accessible aux débutants, y compris les personnes DV apprenant la programmation. |
| C-10 | **Sandbox isolé** : les mini-jeux n'accèdent ni au firmware ni aux fichiers hors de leur dossier | Sécurité : un mini-jeu tiers ne doit pas corrompre le système ni les données d'autres jeux. |
| C-11 | **Communication via USB CDC** : port série virtuel entre la console et l'IDE | Protocole simple et universel, sans driver spécifique. Interface de transfert entre l'IDE et le firmware. |
| C-12 | **Stockage amovible** : assets et mini-jeux sur carte micro SD | Permet de mettre à jour le contenu sans reflasher le firmware; facilite le développement et les tests. |

---

## 3. Contraintes financières

| ID | Contrainte | Justification |
|----|---|---|
| C-13 | **Budget <= 500$ CAD** : prototype, incluant une réserve de ~30% pour imprévus | Aucune contribution financière des départements pour les projets PMC (Guide 2.2); autofinancement ou partenaire. |
| C-14 | **Coût de production cible < 100$ CAD** : par unité | Pour rendre la console accessible vs. les solutions existantes (> 300$). |
| C-15 | **Achats tracés** : factures conservées et consignées dans un rapport de dépenses | Exigence du guide étudiant (section 2.2.2) pour la gestion financière. |

---

## 4. Contraintes temporelles

| ID | Contrainte | Justification |
|----|---|---|
| C-16 | **3 sessions** : S6 (été 2026), S7 (hiver 2027), S8 (automne 2027) | Cadre du cours PMC660-760-860. Non modifiable. |
| C-17 | **540h/personne** : 135h (S6) + 270h (S7) + 135h (S8) sur les 3 sessions | Estimé du guide étudiant : 135h par tranche de 3 crédits (S6=3cr, S7=6cr, S8=3cr). |
| C-18 | **Interfaces gelées avant le développement** : fin de la semaine 2 | Tout retard dans la définition des interfaces bloque le développement parallèle de tous les blocs. |
| C-19 | **Protocole d'essai >= 2 semaines avant tout test** : du prototype | Exigence du guide (section 2.1.5). Tester sans protocole approuvé est une faute grave. |
| C-20 | **Formulaire CER >= 4 semaines avant tout test DV** : avec des personnes vulnérables | Exigence du guide (section 2.1.4). Le CER peut prendre 1-2 semaines, plus si un CER complet est requis. |

---

## 5. Contraintes réglementaires et légales

| ID | Contrainte | Justification |
|----|---|---|
| C-21 | **Cession de droits signée** (Annexe A) : l'UdeS est propriétaire du prototype pendant le projet | Exigence PMC. Sans signature → note "Incomplet" (IN). Le prototype est restitué à la fin. |
| C-22 | **Convention de partenariat signée avant tout legs** au partenaire (SARIC) | Exigence du guide (section 2.1.2, étape 5). Protection légale et assurance. |
| C-23 | **Approbation éthique du CER** : pour les tests avec personnes vulnérables (non-voyantes) | Les personnes DV sont une population vulnérable; le CER évalue les risques et approuve le protocole. |
| C-24 | **Santé et sécurité UdeS** : Politique 2500-004 et Directive 2600-042 | Obligation légale pour tout travail en laboratoire ou atelier de l'UdeS. |
| C-25 | **Composants sous licence libre** : compatible avec la publication open-source | Le projet est open-source (R-61). Tout composant propriétaire est incompatible. |

---

## 6. Contraintes matérielles et de fabrication

| ID | Contrainte | Justification |
|----|---|---|
| C-26 | **Boîtier en impression 3D FDM** : PLA ou PETG | L'équipe dispose de ses propres imprimantes 3D et accède à celles de la Faculté. Pas de budget pour l'injection. |
| C-27 | **PCB fabriqué en externe** : JLCPCB, PCBWay ou équivalent | La Faculté ne fabrique pas de PCB multicouches. Délai typique : 2-3 semaines. |
| C-28 | **Soudure et assemblage à l'UdeS ou chez le partenaire** | Exigence d'assurance (Guide 2.1.7). Les activités hors UdeS/partenaire ne sont pas couvertes. |
| C-29 | **Taille tenant en main** : largeur <= 16 cm | Contrainte ergonomique pour une manette portable. Au-delà, la prise en main devient inconfortable. |

---

## 7. Contraintes de contenu et de propriété intellectuelle

| ID | Contrainte | Justification |
|----|---|---|
| C-30 | **Assets audio libres ou produits par l'équipe** : licence libre (CC0, CC-BY) ou créations propres | Le projet est open-source; des assets sous copyright rendraient la redistribution illégale. |
| C-31 | **IDE intégré au projet** : développé, accessible et fonctionnel pour la livraison | L'IDE permet aux utilisateurs (y compris non-voyants) de programmer et transférer des mini-jeux. Indissociable de NATHAN. |
| C-32 | **PI gérée par la convention SARIC** : et la cession de droits UdeS | Pendant le projet, l'UdeS est propriétaire; à la fin, l'équipe/le partenaire récupère les droits. |

---

*Document vivant — à mettre à jour si une contrainte change (avec justification et accord des parties concernées).*

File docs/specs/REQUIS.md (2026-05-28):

# Requis — Projet NATHAN Console v2.0

**Date :** 2026-05-28
**Session :** PMC660 (S6, E2026)

> Ce fichier regroupe les **requis haut niveau** du projet.
> Les requis définissent **ce que** le système doit accomplir, pas **comment** (pas de choix de composants).
> Voir `BESOINS.md` pour les besoins en amont, `TACHES.md` pour les tâches détaillées.

---

## Légende

| Priorité | Description |
|---|---|
| **E** | Essentiel : MVP, doit être livré |
| **I** | Important : attendu mais non bloquant |
| **S** | Souhaitable : si le temps le permet |

---

## 1. Requis fonctionnels — Expérience utilisateur

| ID | Requis | Priorité | Critère de validation |
|----|---|---|---|
| R-01 | **Jeu sans retour visuel** : le joueur peut jouer à un jeu complet uniquement par le son et le toucher | E | 1 personne non-voyante complète une session de 15 min sans assistance |
| R-02 | **Localisation sonore 3D** : le joueur localise la direction d'un son dans l'espace grâce à l'audio binaural au casque | E | 3/3 testeurs localisent une source sonore avec une erreur < 30° |
| R-03 | **Feedback haptique directionnel** : le joueur sent la direction d'un contact physique (bâton, mur) | E | Un testeur identifie la direction (gauche/centre/droite) dans 4/5 cas |
| R-04 | **Navigation inter-pièces** : le joueur se repère entre les pièces grâce aux signatures musicales des zones adjacentes | E | Un joueur aux yeux bandés identifie >= 3 pièces par leur son depuis le couloir |
| R-05 | **Bâton d'aveugle virtuel** : le joueur détecte les obstacles avec un retour sonore et haptique selon la surface touchée | E | Le joueur distingue >= 3 types de surfaces par le son et le toucher |
| R-06 | **Apprentissage rapide** : un nouveau joueur comprend les contrôles de base en < 5 min grâce à un tutoriel audio intégré | E | 2 nouveaux joueurs naviguent de façon autonome en < 5 min |
| R-07 | **Mini-jeux tiers** : le joueur peut programmer et jouer à des mini-jeux créés par des tiers (MicroPython) | I | Un mini-jeu écrit par un tiers fonctionne sans modification du firmware |

---

## 2. Requis fonctionnels — Contenu de jeu

| ID | Requis | Priorité | Critère de validation |
|----|---|---|---|
| R-08 | **Zones jouables** : le jeu comporte >= 4 zones distinctes jouables (sur 6 planifiées) | E | 4 zones avec ambiance propre et >= 2 interactions chacune |
| R-09 | **Identité sonore par zone** : chaque zone a une ambiance sonore unique et reconnaissable | E | 3/3 testeurs identifient au moins 3 zones par leur son seul |
| R-10 | **Instrument jouable** : le jeu inclut au moins un instrument de musique jouable (guitare ou batterie) | I | Un joueur produit une séquence musicale reconnaissable |
| R-11 | **Mini-jeux d'exemple** : le système inclut >= 2 mini-jeux démontrant l'API MicroPython | I | 2 mini-jeux jouables depuis le hub de la Salle de Mini-Jeux |
| R-12 | **Banque de sons** : la banque contient >= 50 sons uniques (ambiances, effets, voix, musiques) | E | Inventaire documenté >= 50 fichiers WAV |
| R-13 | **Narration audio** : le jeu inclut une narration pour le tutoriel et les instructions | E | >= 10 clips de narration intégrés |

---

## 3. Requis de performance

| ID | Requis | Priorité | Critère de validation |
|----|---|---|---|
| R-14 | **Sources spatiales simultanées** : le système supporte >= 4 sources sonores spatiales sans artefact audible | E | 4 sources jouent en simultané pendant 1 min sans coupure ni distorsion |
| R-15 | **Latence audio** : la latence bout-en-bout (action → son au casque) est < 50 ms | E | Mesure instrumentée < 50 ms |
| R-16 | **Latence haptique** : la latence (action → vibration moteur) est < 100 ms | E | Mesure instrumentée < 100 ms |
| R-17 | **Fréquence de polling** : le polling des entrées est >= 100 Hz | E | Intervalle moyen entre lectures < 10 ms |
| R-18 | **Stabilité** : aucun crash ni fuite mémoire pendant 1h de jeu continu | E | Test de stabilité de 1h sans crash; heap libre stable |
| R-19 | **Temps de démarrage** : le boot prend < 5 secondes du power-on au menu principal | I | Mesure au chronomètre < 5 s |

---

## 4. Requis hardware (caractéristiques, sans choix de composants)

| ID | Requis | Priorité | Critère de validation |
|----|---|---|---|
| R-20 | **Joysticks** : 2 joysticks analogiques double-axe avec bouton intégré | E | 4 axes analogiques + 2 clicks lus par le firmware |
| R-21 | **Boutons** : >= 7 boutons numériques (A, B, C, L1, R1, Start, Select) | E | Chaque bouton détecté sans ambiguïté par le firmware |
| R-22 | **Moteurs haptiques** : >= 5 moteurs de vibration en arc, contrôlables individuellement en intensité | E | 5 moteurs vibrent indépendamment à des intensités différentes |
| R-23 | **Sortie audio** : stéréo via jack 3.5mm, qualité suffisante pour le HRTF binaural (>= 44.1 kHz, >= 16 bits, SNR > 80 dB) | E | Son spatial perceptible au casque; pas de bruit de fond gênant |
| R-24 | **Alimentation** : batterie rechargeable via USB-C | E | Autonomie >= 4h en usage typique; charge par USB-C |
| R-25 | **Stockage amovible** : assets et mini-jeux sur support amovible (carte SD ou équivalent) | E | Lecture de fichiers WAV depuis le stockage |
| R-26 | **Communication PC** : la console communique avec un PC via USB (port série virtuel) | E | Transfert bidirectionnel fonctionnel via USB |
| R-27 | **Ergonomie** : la console tient dans les mains d'un adulte (largeur <= 16 cm) | E | 3/3 testeurs confortables après 30 min |
| R-28 | **Contrôles au toucher** : tous les contrôles sont différentiables au toucher sans retour visuel | E | 5/5 identifications correctes par un testeur les yeux bandés |
| R-29 | **Fabrication 3D** : le boîtier est fabricable par impression 3D FDM | E | Impression réussie, assemblage sans outil spécialisé |
| R-30 | **Choix du MCU mesuré** : le microcontrôleur est choisi selon les besoins réels mesurés (CPU, RAM, I/O) après le développement PC | E | Document de justification basé sur le benchmark du jeu sur PC |

---

## 5. Requis d'architecture logicielle

| ID | Requis | Priorité | Critère de validation |
|----|---|---|---|
| R-31 | **Game engine agnostique** : le moteur est indépendant du matériel via des interfaces abstraites (entrées, son, haptique, stockage) | E | Le même code de jeu fonctionne avec une manette PS4/Xbox sur PC ET avec la manette finale |
| R-32 | **Deux implémentations par interface** : chaque interface a >= 2 implémentations (dev PC + matériel final) | E | Swap d'implémentation sans recompilation du game engine |
| R-33 | **Interfaces gelées tôt** : les interfaces sont définies et gelées avant le développement (Phase 0) | E | Fichiers de contrat signés par les équipes concernées |
| R-34 | **Sandbox mini-jeux** : les scripts MicroPython s'exécutent dans un sandbox isolé | E | Script exécuté; tentative d'accès hors sandbox bloquée |
| R-35 | **API `nathan.*`** : expose audio (play, stop, set_ambient), haptic (pulse, sweep), input (joystick, button), game (score, end) | E | Chaque fonction appelable depuis un script MicroPython |

---

## 6. Requis de l'IDE de programmation

L'IDE fait partie intégrante du projet. Architecture en 5 couches : UX accessible → Édition → Assistant IA → Déploiement → Matériel.

### 6.1 Couche UX accessible

| ID | Requis | Priorité | Critère de validation |
|----|---|---|---|
| R-36 | **TTS français** : l'IDE vocalise tout feedback, diagnostic et navigation en français | E | Chaque action de l'éditeur produit une annonce vocale pertinente en fr-FR |
| R-37 | **Lecteur d'écran et clavier** : compatible ARIA et navigable entièrement au clavier | E | Un utilisateur DV écrit du code et transfère un fichier sans aide visuelle |
| R-38 | **Shell vocal (STT)** : l'utilisateur peut dicter des commandes ou du code | I | Commande vocale "ouvrir fichier main.py" exécutée correctement |
| R-39 | **Mode d'affichage accessible** : grand texte, contraste élevé | I | Police et contraste ajustables; lisible à 200% de zoom |
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

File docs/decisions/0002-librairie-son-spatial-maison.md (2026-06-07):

# ADR-0002 — Développer notre propre librairie de son spatial (HRTF maison)

- **Statut :** Accepté
- **Date de la décision :** 2026-06-07
- **Décideurs :** AUD, ENG
- **Contexte projet :** S6, cœur du produit
- **Liens :** R-14, R-23, C-08, [[specs/HYPOTHESES]] (H-07), [[planning/ESTIMATION]] §2, [[planning/TACHES]] Bloc 2 (`TECH-13`, `TECH-14`, `AU-03`, `S7-T01`, `S8-T02`), [[0004-option-repli-audio-fpga]]

## Contexte et problème

Le cœur du produit est le **rendu binaural HRTF temps réel**. La cible finale est embarquée (MCU), avec une possible décharge matérielle (ADR-0004). Il faut un moteur audio **portable et maîtrisé**.
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

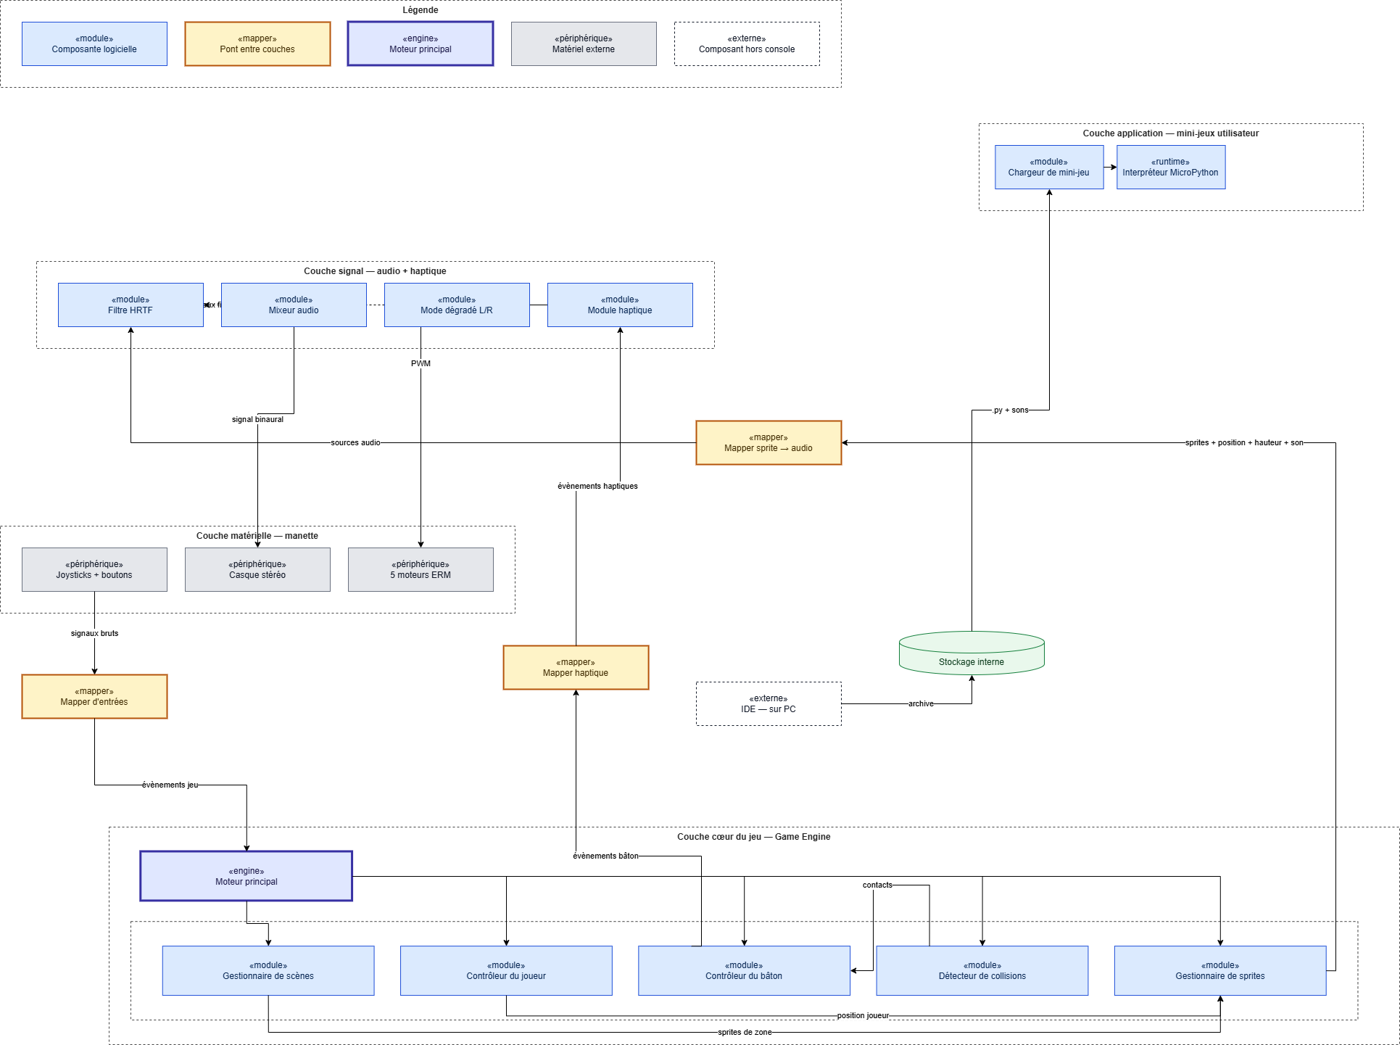
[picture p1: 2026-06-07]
docs/architecture/console.drawio.png

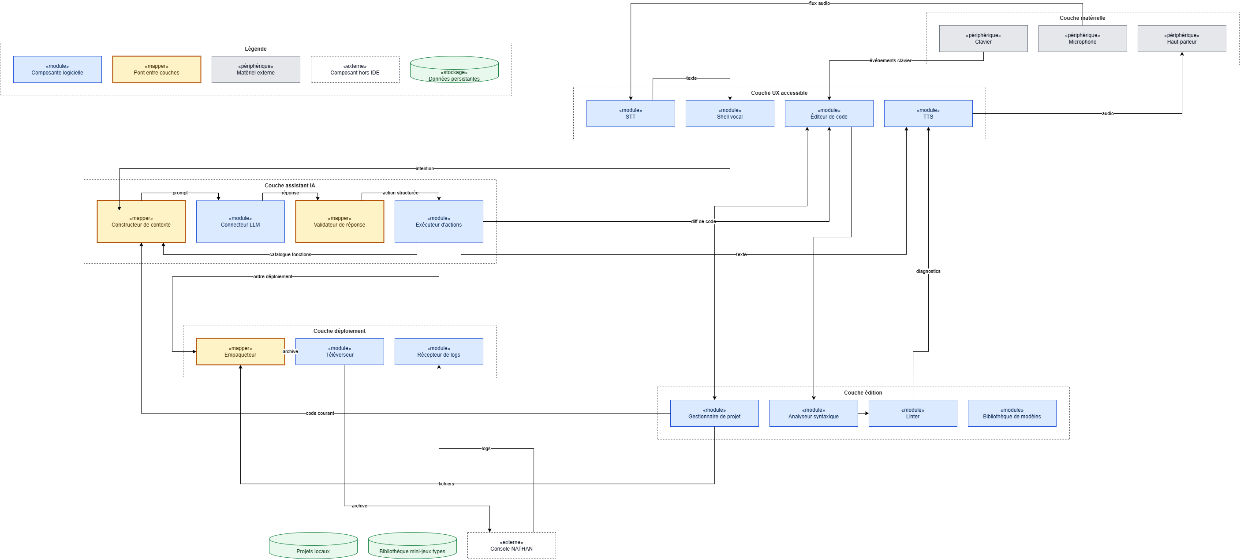
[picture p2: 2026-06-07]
docs/architecture/ide.drawio.png

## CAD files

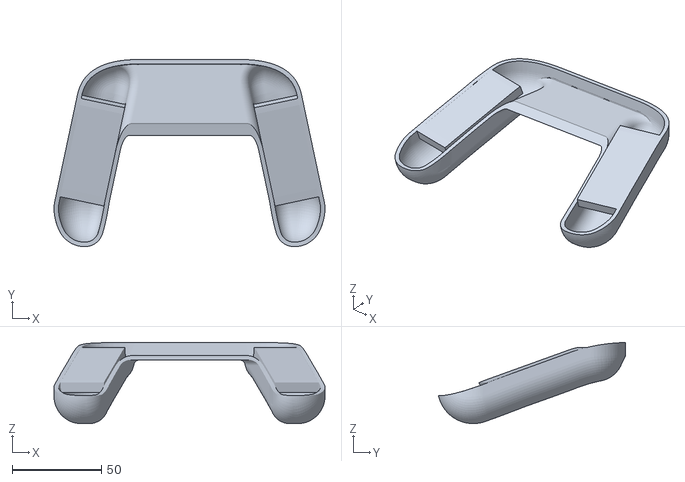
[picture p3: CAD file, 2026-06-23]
3D Print Models/Manette V1.0/Manette V1.0 - Dessous.stl
152.1 x 105.0 x 45.5

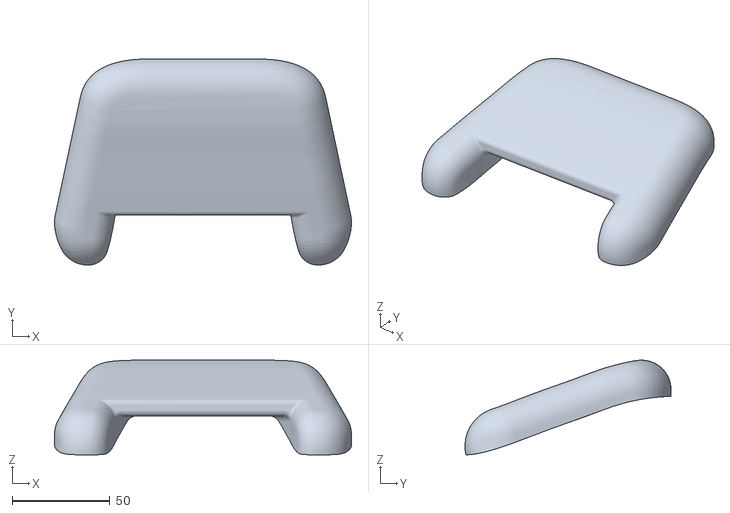
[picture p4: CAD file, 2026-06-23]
3D Print Models/Manette V1.0/Manette V1.0 - Dessus.stl
152.1 x 105.5 x 48.5

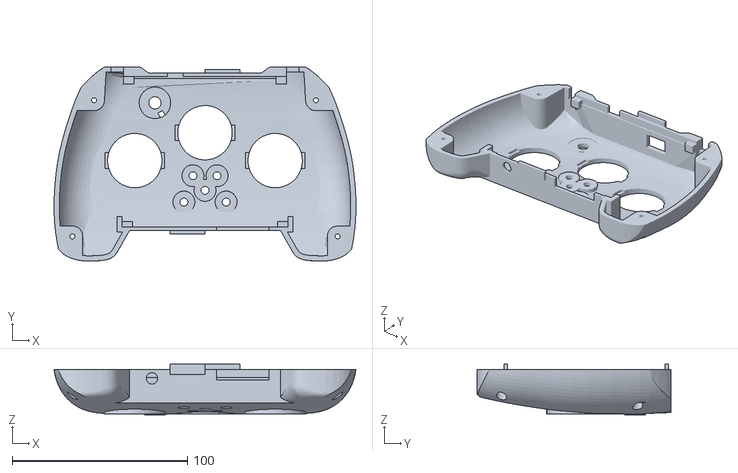
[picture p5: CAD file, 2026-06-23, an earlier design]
3D Print Models/Manette V0/NATHAN-Rear-console.STL
172.1 x 110.7 x 29.0

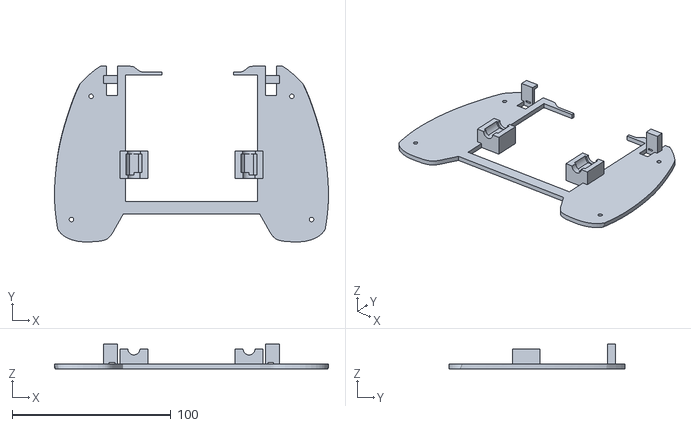
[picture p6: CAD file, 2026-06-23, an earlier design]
3D Print Models/Manette V0/NATHAN-Middle-console.STL
172.5 x 110.6 x 15.5

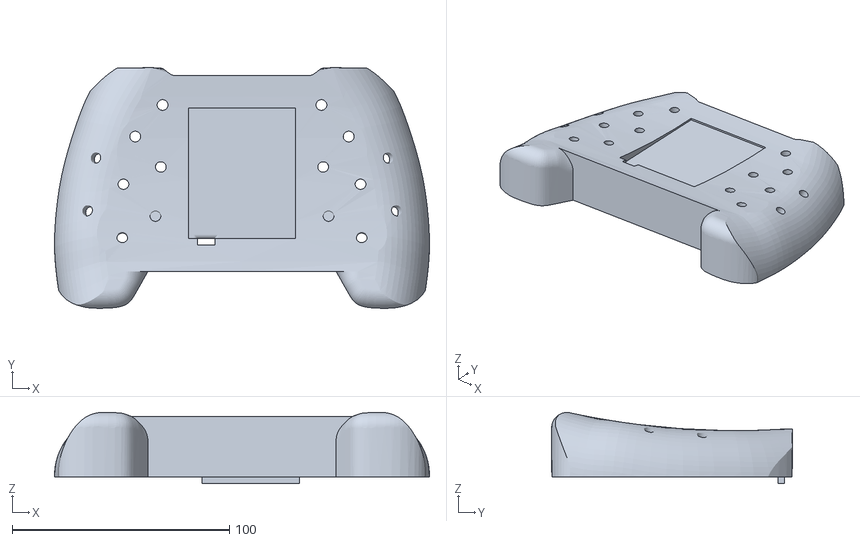
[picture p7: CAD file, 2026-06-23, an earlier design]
3D Print Models/Manette V0/NATHAN-Front-console.STL
172.5 x 110.7 x 32.7

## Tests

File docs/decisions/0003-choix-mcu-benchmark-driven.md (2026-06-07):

# ADR-0003 — Choix du MCU piloté par benchmark (3 gammes, pas de pré-sélection)

- **Statut :** Accepté
- **Date de la décision :** 2026-06-07
- **Décideurs :** TOUTES
- **Contexte projet :** S6 (stratégie) → décision effective à `S7-T06`
- **Liens :** C-06, C-07, R-30, [[planning/ESTIMATION]] (document entier), [[planning/TACHES]] (`S7-T04`, `S7-T05`, `S7-T06`, `MIP-08`, `MIP-09`)

## Contexte et problème

Le MCU **dimensionne tout** (CPU et RAM pour le HRTF temps réel). Le choisir trop tôt, sans données, risque de sur-dimensionner (coût) ou sous-dimensionner (échec). Le guide pousse à une démarche d'estimation rigoureuse.

## Options envisagées

- **A — Choisir le MCU d'emblée** (p. ex. RP2350 car le moins cher, ou ESP32-S3 car bien connu). *Contre :* décision non informée, risque élevé, contraire à l'esprit d'ingénierie attendu.
- **B — Estimer puis mesurer (retenue) :** garder **3 gammes ouvertes** (A : RP2350 / B : ESP32-S3 / C : STM32H7), développer sur PC, puis **trancher après un benchmark PC mesuré** (`S7-T04` → `S7-T05` → décision `S7-T06`).

## Décision

**Aucun pré-choix.** Le MCU est sélectionné au jalon `S7-T06` à partir d'un **document de justification quantitatif** alimenté par le benchmark PC. `ESTIMATION.md` estime l'espace des solutions (perf, RAM, budget, effort de portage) sans le pré-déterminer.

## Conséquences

- **+** Décision factuelle, options ouvertes, budget non bloquant (les 3 gammes < 500 $).
- **−** Exige que le moteur audio et l'engine soient **prêts à temps** pour le benchmark (le calendrier avance ce jalon à ~S7 sem 5 ; voir notes de planification dans `TACHES.md`).

## Suivi / quand re-questionner

Le résultat de `S7-T06` (MCU effectivement retenu) et de `S7-T07` (chemin audio : software / DSP / FPGA) feront chacun l'objet d'un **nouvel ADR** documentant le choix réel.

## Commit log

2026-05-28 feat: add project management documents (requis, taches, cadre logique, besoins, contraintes, hypotheses)
    Add 6 structured project management files for PMC660:
    - REQUIS.md: 59 high-level requirements organized by subsystem
    - TACHES.md: complete task breakdown across 3 sessions (S6-S8) with parallel workflows, critical paths, and Xbox-to-NATHAN controller transition
    - CADRE-LOGIQUE.md: logical framework with measurable indicators (4 levels)
    - BESOINS.md: 29 stakeholder needs with requirements traceability
    - CONTRAINTES.md: 32 fixed constraints (accessibility, technical, financial, regulatory)
    - HYPOTHESES.md: 32 work hypotheses with validation dates and contingency plans
    Key design decisions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
2026-05-28 fix: update CAHIER-DES-CHARGES to reflect project changes (IDE integrated, DV user group via APHVE, remove personal names)
2026-05-28 refactor: streamline CAHIER-DES-CHARGES with project management documents
    - Remove hardcoded component choices (ESP32-S3, PCM5102A) — MCU now chosen after benchmark
    - Replace sections 11-14 (risks, planning, budget, deliverables) with references to dedicated files
    - Remove personal names, update IDE as integral part of project
    - Add MCU candidate comparison table with requirements-based specs
    - Net reduction: 448 lines removed, 109 added (less duplication with REQUIS/TACHES/CONTRAINTES/HYPOTHESES)
2026-06-07 docs: tracabilite des decisions (ADR) et reorganisation docs/
    Reorganisation: specs, planification, decisions et architecture regroupes sous docs/ (git mv, historique preserve).
    Journal de decisions ADR 0001-0007 + index: architecture PC-first et contrats d'interface, librairie de son spatial maison, choix du MCU pilote par benchmark, option de repli audio materielle FPGA/CP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
    OPTION-AUDIO-MATERIELLE.md fusionne dans ADR-0004.
    Ajout docs/README.md (onboarding) et CONTRIBUTING.md (processus de decision + conventions).
    Diagrammes d'architecture (console, IDE) versionnes dans le repo.
    TACHES.md: planification GAN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
2026-06-07 docs: re-calage GANTT de TACHES sur le 8 juin + conformite Annexe L/M
    Re-baseline: aucune tache incomplete datee avant le 8 juin (seuls coachings 1-3 et PART-01/02 faits).
    Sequence S6: MIP finalise s6, formative 11 juin, remise finale 18 juin; technique demarre s8 (blitz audio+engine, 1 pers. boitier); RPC1+RAE fin S6 (s15).
    Partenariat: ouverture dossier SARIC 11 juin, convention ~septembre, recrutement DV apres la convention (T4).
    PCB preliminaire et contenu de jeu reportes en stage T4.
    Conformite (Annexe L/M): FEPRAP, audit numerique S6 et S7 x2, page descriptive (Annexe Z), mise en garde (Annexe I), declaration ressources (Annexe Y), ponderations corrigees, tableau de bord jeudi 5h00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
2026-06-07 docs: colonne Periode (S6/T4/S7/T5/S8) dans les tableaux; ADM-01 a ADM-06 faites
    Colonne Periode (session/stage) ajoutee a tous les tableaux de taches pour une lecture humaine rapide du 'quand'; les dates ISO restent pour JIRA.
    ADM-01 a ADM-06 (formalites contractuelles) marquees faites.
2026-06-07 docs: schemas Mermaid (architecture, Gantt, chemin critique) dans TACHES
    Conversion des 3 diagrammes ASCII de la Partie 3 en Mermaid (rendu natif GitHub): architecture en blocs/interfaces (flowchart), echeancier visuel (gantt par session/stage avec jalons et chemin critiq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
2026-06-07 fix: rendu Mermaid du diagramme de bloc (architecture) - aretes explicites, classDef sans dasharray
    Le diagramme 'Architecture en blocs' ne rendait pas sur GitHub a cause du fan-out 'A --> B & C' et de 'stroke-dasharray:5 5' (espace) dans classDef. Reecrit en arretes explicites + classDef fill/stroke seulement.
2026-06-07 chore: ignorer verrous KiCAD/stackdumps/backups + retrait d'un verrou obsolete
2026-06-08 docs: corrige l'effectif d'équipe 7 -> 8 et recalcule les totaux d'heures
    Effectif: 7 -> 8 membres (CADRE-LOGIQUE I1, HYPOTHESES H-24, en-tete
    TACHES, ESTIMATION). Heures/personne inchangees (fixees par C-17);
    seuls les totaux d'equipe = heures/pers x 8 changent:
    - S6/S8 945 -> 1080 h, S7 1890 -> 2160 h, T4/T5 ~420 -> ~480 h
    - 3 sessions 540x7=3780 -> 540x8=4320 h, restantes S6 ~630 -> ~720 h
    - tableau des flux ESTIMATION re-echelonne x8/7 (% inchanges, somme 4320)
    - verdict T4 ajuste: passe de sur-souscrit a dans sa capacite (marge mince)
2026-06-09 fix: ajuste le pourcentage de temps estimé pour le flux C — Hardware (ELEC)
2026-06-10 fix: mise à jour des détails des modèles 3D boîtier et changement de référence à Onshape
2026-06-14 chore(gestion): deplacer l'outillage de gestion de projet vers le repo NATHAN-Gestion
    Le socle JIRA-sync, le tableau de bord PM, l'outillage de migration et les
    documents de planification ont ete extraits dans le depot dedie NATHAN-Gestion.
    Effet net cote NATHAN-console : retrait de docs/planning/TACHES.md et
    ESTIMATION.md (desormais maintenus dans NATHAN-Gestion) + mise a jour du .gitignore.
2026-06-23 Déplacement de l'ancienne mannette dans son propre dossier
    Le dossier est nommé la "Manette V0".
    [NATHAN-Front-console.STL, NATHAN-Middle-console.STL, NATHAN-Rear-console.STL]
2026-06-23 Manette V1.0
    Ajout de la version imprimée pour seulement faire les premiers tests de confort.
    [Manette V1.0 - Dessous.stl, Manette V1.0 - Dessus.stl]
